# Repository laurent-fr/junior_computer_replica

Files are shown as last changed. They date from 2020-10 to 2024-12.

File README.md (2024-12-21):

# Junior Computer Replica

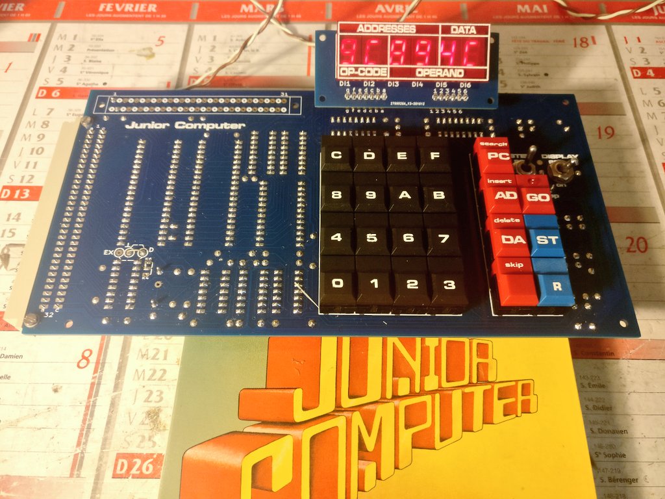
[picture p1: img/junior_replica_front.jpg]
Junior Computer Front


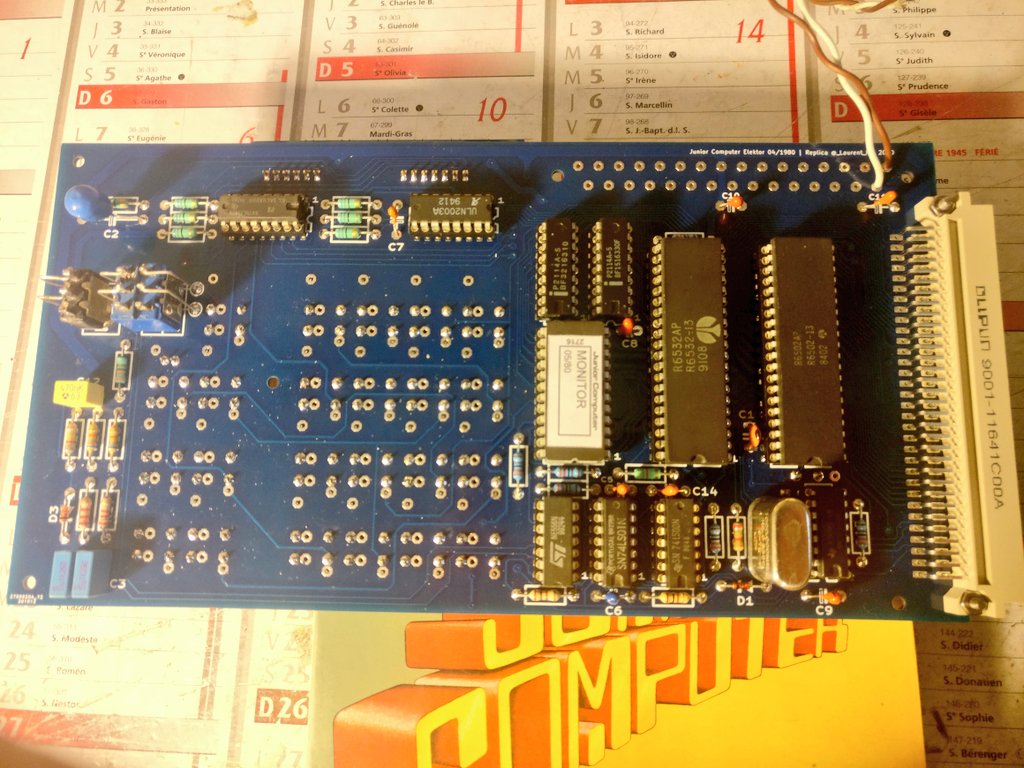
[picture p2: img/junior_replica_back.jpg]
Junior Computer Back


The Junior Computer is a 6502 SBC made by Elektor in 1980. It looks a lot like a KIM-1.

This is a replica PCB I made with KiCAD.

The best source of information for this computer is Elektor Magazine from 80's , but you can find a lot on this website : http://retro.hansotten.nl/6502-sbc/elektuur-junior/

This board is not a 100% accurate replica, because I have added directly on the PCB a few updates published later by Elektor :
* a fix for memory decoding needed for the expansion board
* the main decoupling capacitor C2 was on wrong side of S25 (activate display) which could reset the computer
* a simple reset circuit with a resistor and a capacitor

I also replaced the 2708 EPROM by a 2716, which avoid the need of an hard to find EPROM & EPROM programmer, and has the big benefit of reducing the required power supplies from 3 (+5,-5,+12) to only +5V.

This work is licenced under CC BY-NC-SA (Attribution-NonCommercial-ShareAlike)

## BOM

| Qty | Reference | Value | Comment |
| --- | --- | --- | --- |
| 1	| C1 |	10p | |
| 1	| C2 |	47µ 6V tantale | |
| 2	| C3, C4 |	100n MKH
| 8	| C5...C9, C10, C11, C14 | 	1µ 16V tantale | |
| 1	| C12 |	470nF MKH | |
| 2	| D1, D3 |	1N4148 | |
| 1	| IC1 |	MC6502 | |
| 1	| IC10 |	74LS01 | |
| 1	| IC11 |	ULN2003 | |
| 1	| IC2 |	2716 | |
| 1	| IC3 |	MC6532 | probably the first part to look at ! |
| 2	| IC4 IC5 |	2114 | static RAM, search on Ebay |
| 2	| IC7 IC6 |	74LS145 | |
| 1	| IC8 |	NE556 | |
| 1	| IC9 |	74LS00 | |
| 1	| J2 |	DIN41612 32 A+C angled male| |
| 1	| J3 |	DIN41617-31 straight female | |
| 2	| R17 R19 |	2k2 | |
| 2	| R18 R20 |	68k | |
| 1 | R1 | 330K | |
| 6	| R2 R3 R4 R16 R14 R15 |	3k3 | |
| 2	| R22 R21 |	1k | |
| 1	| R23 |	820k | |
| 1	| R5 |	4k7 | |
| 1	| R6 |	330 | |
| 7	| R7 R8 R9 R10 R12 R13 R11 |	68 | |
| 21	| S1…S23 |	Digitast 12.7mm | 16 black, 4 red, 1 red with integrated LED, 2 blue, but see below |
| 1	| S24 | DPDT lever switch	| with soldering lugs |
| 1	| S25|	SPDT lever switch | with soldering lugs |
| 1	| X.Tal1 |	1Mhz | can be hard to find ! |
| 3	| Socket DIP-14	| | |
| 3	| Socket DIP-16	| | |
| 2	| Socket DIP-18	| | |
| 1	| Socket DIP-24	| | |
| 2	| Socket DIP-40	| | |
| 6 | Di1 ... Di6 | MAN4640A | 7 segment display |

IF you cannot find 2114 RAMs , you can try the small board on "board adapter" folder (warning : not tested !) which should allow to use a 6116 RAM instead and plugs into the 2114 sockets

The Digitast keys (https://www.digikey.com/catalog/en/partgroup/digitast-series/15959) are the most expensives parts of this project. You can also use square tactile switchs instead (but it's not as pretty !)

An other thing to consider is the marking : the black keys need white marking, which can be hard to do. So think of how you will do the marking before choosing the colors of the keys !

## Ordering the PCB

Use you favorite online PCB seller, and order 2 double-sided PCBs (display + computer) from the KiCad output files.

The real ones from Elektor where blue on component side and red on solder side, but if you order a blue PCB it will be close enough (and very nice).

## Building the computer

The building is pretty straightforward (look at the original documentation). Components are soldered on one side, buttons and disply on the other side.

S24 and S25 switchs needs wires from the switchs lugs to the PCB (I used cutoff of resistor leads)

To connect the display to the main board, I used long SIL connectors (15-20mm long) soldered on both side, then I bent the display to ~30°

Don't forget the two small wire jumpers on front side : one from ground to letter "D" and the other one from K6 to the center pin.

If you want to use the file sticker-juniorcomputer.svg, first install the font "Microgramma D Extended Bold" on your system.

## Programming the EPROM

I use a TL866 II plus for this, but anything that works is OK. 

Program the 2716 with the file 2716_junior_monitor_ram_05_1980.bin

## First tests

The power supply is available on both connectors, you just need 0v and +5V (1amp should be more than enough).

All the display should light up (check that the DISPLAY switch is ON). If you see some display ON, some display OFF, it could be a bad MC6532 (don't ask how I know that ...)

If nothing happens, press the reset switch to start the computer.

Typing numbers on keyboard should update the display.

You can find test programs on http://retro.hansotten.nl

## Going further

It would be great to be able to load and save data, and also to have a serial terminal for typing programs. It's exactly the purpose of the Junior Interface board ! Look into the folder "junior-interface" for more infos !

Now I'm sure you want to run BASIC on the Junior, no problem, just build the memory expansion from "junior-universal-memory" folder and you're good to go !

## Status

### Working

* junior-computer : the computer, built and tested OK
* junior-computer-display: the 7 segments display, built and tested OK
* junior-interface : the 2nd board adding various I/O to the computer, built and tested OK
* junior-internal-conn : internal bus between computer and interface, built and tested OK
* junior-internal-bus : a small PCB for linking the computer and the interface board, built and tested OK
* junior-bus : Elektor expansion bus. Not tested, built and tested OK
* junior-universal-memory : a RAM/EPROM board for the computer, built and tested OK

### Not tested

* ram-adapter : replace 2x2114 by 1x6116 RAM. Not tested

```
Any question ? --> Mastodon @LaurentFr@piaille.fr
```

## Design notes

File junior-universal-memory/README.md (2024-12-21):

# Universal Memory

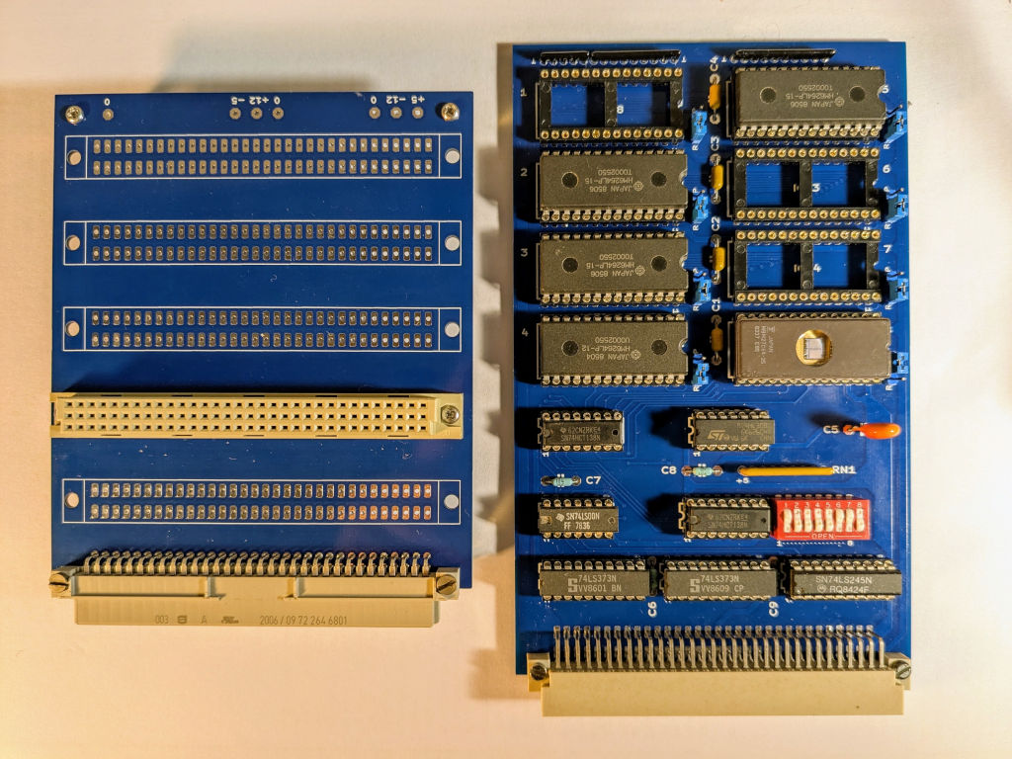
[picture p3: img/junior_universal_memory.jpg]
Universal Memory Card


This board is inspired by Elektor Universal Memory Card published in 1983 http://retro.hansotten.nl/uploads/junior/articlesuk/universalmemoryuk198303.pdf with a different address decoding.

## BOM

| Qty | Reference | Value | Comment |
| --- | --- | --- | --- |
| 8	| C1...C4,C6...C9 | 100n | |
| 1	|C5 | 10µF/16V | |
| 2	| IC1,IC2 |	74LS373 | |
| 1	| IC3 | 74LS245 | |
| 2	| IC4,IC5 | 74LS138 | |
| 1	| IC6 | 74LS00 | |
| 1	|IC7 | 74LS30 | |
| 8	| IC8...IC15 | 6264 and/or 27C64 | see Setup below ! |
| 1	| | Din 41612 male angled | |
| 2	| RN1 | Resistor Network 8x10K | total 9 pins | 
| 1 | |	Resistor Network 8x100K | total 9 pins |
| 1	| | Resistor Network 9x100K | total 10 pins |
| 1	| | Resistor Network 4x100K | total 5 pins |
| 1	| SW1 | DIL switch x8 | |

## Building the board

- be careful about resistor networks orientation
- if you cannot find the various 100K resistor networks you can instead use standard 100K resistors soldered vertically with a common lead on top

You also need to build the "junior-bus" project.

## Setup

You have 8 sockets available, where you can install either 8Kb RAMs (6264) or 8Kb EPROMs (27c64). Each socket is numbered from 1 to 8 and corresponds to 1/8 of total memory space : 

| Socket # | Memory range |
| --- | --- |
| 1 | 0x0000 to 0x1FFF |
| 2 | 0x2000 to 0x3FFF |
| 3 | 0x4000 to 0x5FFF |
| 4 | 0x6000 to 0x7FFF |
| 5 | 0x8000 to 0x9FFF |
| 6 | 0xA000 to 0xBFFF |
| 7 | 0xC000 to 0xDFFF |
| 8 | 0xE000 to 0xFFFF |

Every time you install a RAM or an EPROM, set the corresponding jumper accordingly (R for RAM and P for (E)PROM).

On SW1, every switch corresponding to an empty socket must be OPENED, close the others.

Socket 1 cannot be used (for now ...) because it's address space is used by the Junior Computer and the interface.

You need to put an EPROM in socket 8 because reset vectors are now handled by this board. You just need to program the 6 last bytes, the remaining space is free to use. By default I suggest putting 0xFF on all un-used bytes.

| EPROM addr | Memory addr | Data |
| --- | --- |  --- |
| 0000 | E000 | FF |
| ... | ... | FF |
| 1FF9 | FFF9 | FF |
| 1FFA | FFFA | 2F |
| 1FFB | FFFB | 1F |
| 1FFC | FFFC | 1D |
| 1FFD | FFFD | 1C |
| 1FFE | FFFE | 32 |
| 1FFF | FFFF | 1F |

To run BASIC you will need at least 2 RAMs in sockets 2&3 (16Kb total), but you will have more space with 4 RAMS (sockets 2 to 5, 32Kb total).

## Junior address decoding update

By default the Junior Computer only decodes 8Kb of memory, ignoring A13,A14 and A15 addresses. This means that every address content is repeated 8 times, every 8Kb. This is why the reset vectors in the Junior EPROM at address 0x1FFE and 0x1FFF are also seen at 0xFFFE and 0xFFFF, which allows the computer to boot.

The problem with this address decoding is that our memory card cannot be seen by the computer, because it cannot see anything above the first 8Kb !

To solve this an improved address decoding has been added to the Junior interface, to activate it you need to do 2 things :

- on the Junior Computer, move the Jumper from GND-D to EX-D
- on the Junior Interface, move the jumper from T-S to S-R

Now the computer is able to decode full 64Kb memory (and won't start without the memory board !)

## Test

Connect the bus to the Junior interface, the the memory card to the bus and power on the computer.
It should start at usual.

With the keypad you can try to read and write memory on addresses corresponding to RAM.

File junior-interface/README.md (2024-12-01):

depp# Junior Computer Replica

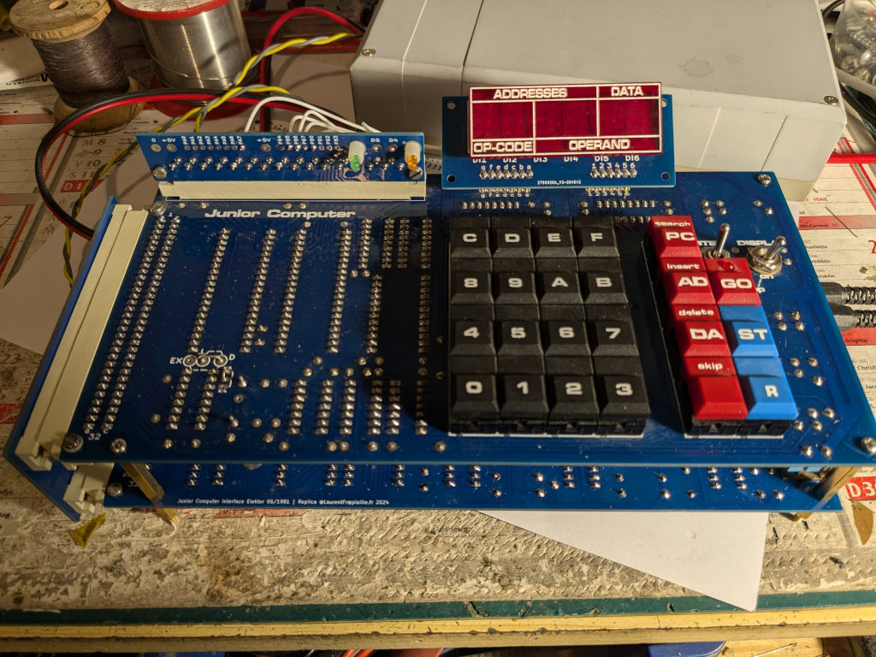
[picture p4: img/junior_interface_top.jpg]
Junior Computer Interface Top Junior Interface Top


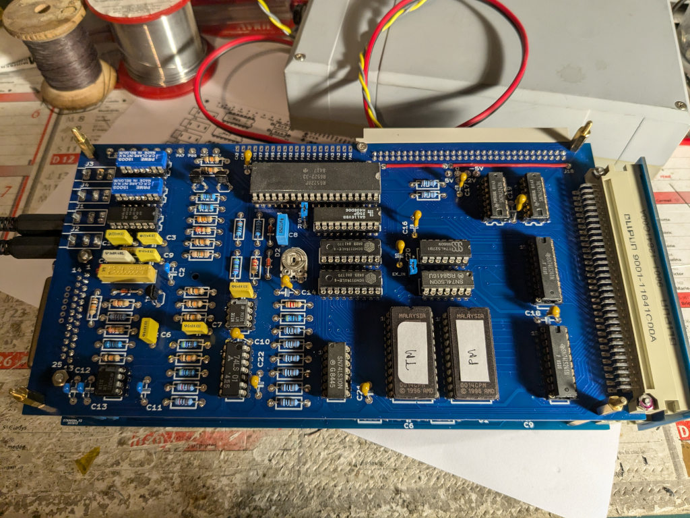
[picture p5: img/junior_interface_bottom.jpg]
Junior Computer Interface Bottom Junior Interface Bottom


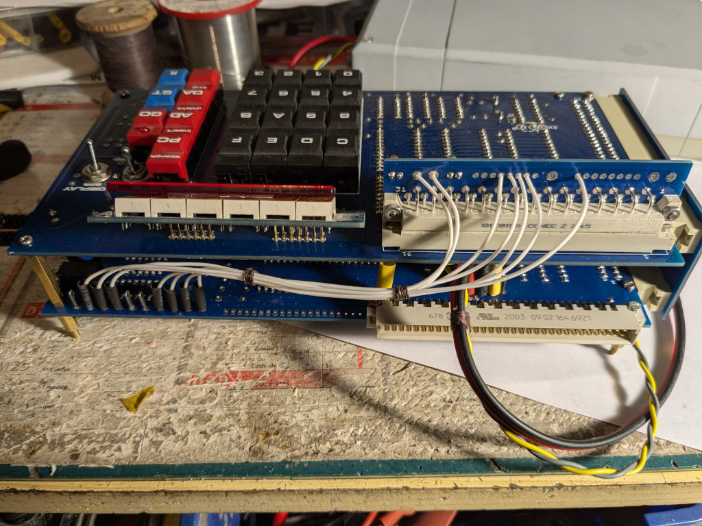
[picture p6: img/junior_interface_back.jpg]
Junior Computer Inerface Back Junior Interface Back


This is a replica of the expansion board for the Junior Computer, published in Elektor magazine in 1981

This is a replica PCB I made with KiCAD.

The best source of information for this computer is Elektor Magazine from 80's , but you can find a lot on this website : http://retro.hansotten.nl/6502-sbc/elektuur-junior/

I made some changes from the original :
* The board can only use 2716 Eproms, no 1K ROM or 1K EPROM 
* The PROM used for bus read/write signals is replaced by a GAL
* The RCA connectors for the tape are replaced by smaller 3.5mm jacks, which allows a better placement of DB25 connector

This work is licenced under CC BY-NC-SA (Attribution-NonCommercial-ShareAlike)

## BOM

| Qty | Reference | Value | Comment |
| --- | --- | --- | --- |
|1	|C1	|220n | |
|4	|C2,C11,C12,C13	|10uF 16V | |
|1	|C3	|22n | |
|1	|C4	|1n | |
|3	|C5,C6,C7	|6n8 | |
|1	|C8	|100n | |
|1	|C9	|47n | |
|10	|C10,C14,C15,C16,C17,C18,C19,C20,C21,C22	|1uF 16V | |
|3	|D1,D2,D3	|1N4148 | |
|1	|IC1	|6522 | |
|2	|IC2,IC3	|2114 | |
|2	|IC4,IC5	|2716 | |
|1	|IC6	|NE565 | |
|2	|IC7,IC8	|LM311 | |
|2	|IC9,IC10	|74LS241 | |
|2	|IC11,IC12	|74LS243 | |
|1	|IC13	|74LS27 | |
|1	|IC14	|74LS01 | |
|1	|IC15	|74LS30 | |
|1	|IC16	|74LS00 | |
|1	|IC17	|GAL16V8 | |
|4	|J1,J2,J3,J4	|Jack 3.5mm |
|1	|J6	|C64AC | |
|1	|J7	|C64AB | |
|1	|J10	|DB25_Female | |
|1	|P1	|5k  multitour | |
|1	|P2	|1k | |
|8	|R1,R2,R3,R4,R32,R33,R34,R35	|1K | |
|1	|R5	|22k | |
|9	|R6,R10,R11,R14,R15,R24,R26,R27,R28	|10k | |
|3	|R7,R8,R36	|8k2 | |
|4	|R9,R18,R22,R23	|4k7 | |
|1	|R12	|6k8 | |
|3	|R13,R25,R31	|2k2 | |
|1	|R16	|100 | |
|1	|R17	|330 | |
|1	|R19	|470 | |
|1	|R20	|1k2 | |
|1	|R21	|15k | |
|1	|R29	|33k | |
|1	|R30	|4M7 | |
|1	|R37	|33 | |
|2	|Re1,Re2	|relay_reed | |
|1	|T1	|BC547 | |
|2	|T2,T3	|BC516 | |

## Building the interface

Nothing special here, juste be careful : J1..J4 , J7 and J10 are on solder side. Do not forget the 2 wires jumpers near J7.

Put a jumper between the center pin and "Ex_in" and an other one between "T" and "S"

You will also need to build the projects "junior-internal-bus" and "junior-interface-conn". 

The internal bus is simply 2 DIN41612 connectors, just be careful to solder the connectors correctly : the ground plane should be on solder side, and look at where are +5V and GND to avoid soldering the board upside down.

The interface connector is a small PCB to connect the top left connector of the Junior Computer to the pins on the interface board. Just put a wire on signals with the same name on both side. You don't need to connect GND and +5V, they are already available on the internal bus.

You will also need a +5V power supply (at least 1A, let's say 2A to be safe) and +12V/-12V (400mA is more than enough).

## Programming 

Program the GAL with the .jed file in the "GAL" folder (again the TL866 II plus can do the job)

Program the 2 eproms "TM" and "PM" with "TM ESS506.bin" and "PM ESS507.bin" from 'eproms' folder

## First tests

Once everything is connected together (look at the pictures on the top of this page), the Junior Computer should power up as usual.

You should be able to read and write data between $0200 and $03FF (the new 1K RAM), and read EPROM data at $0800 and $1000 (compare the firsts bytes with the .bin files contents)

To setup the tape and the serial interfaces, you can follow the original articles availble at http://retro.hansotten.nl/6502-sbc/elektuur-junior/elektor-junior-literature/

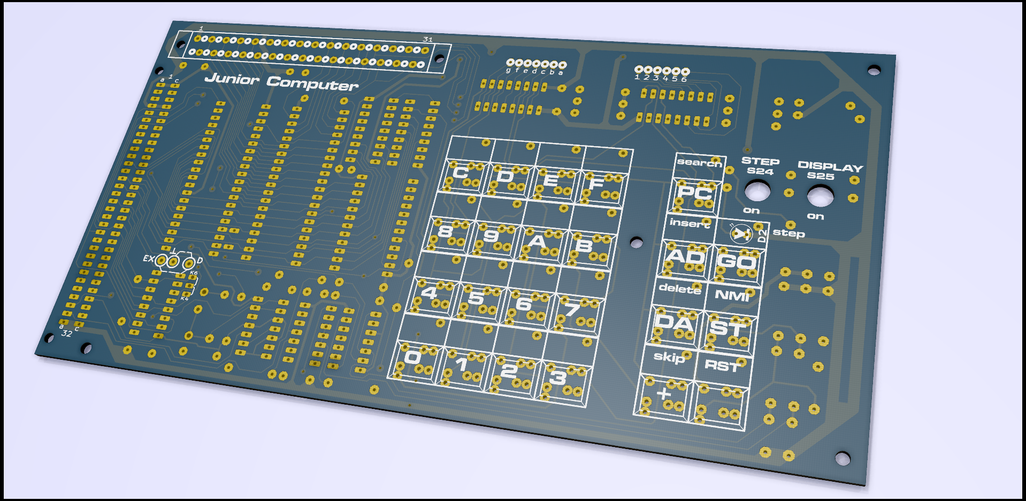
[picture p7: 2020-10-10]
junior-computer-1.png

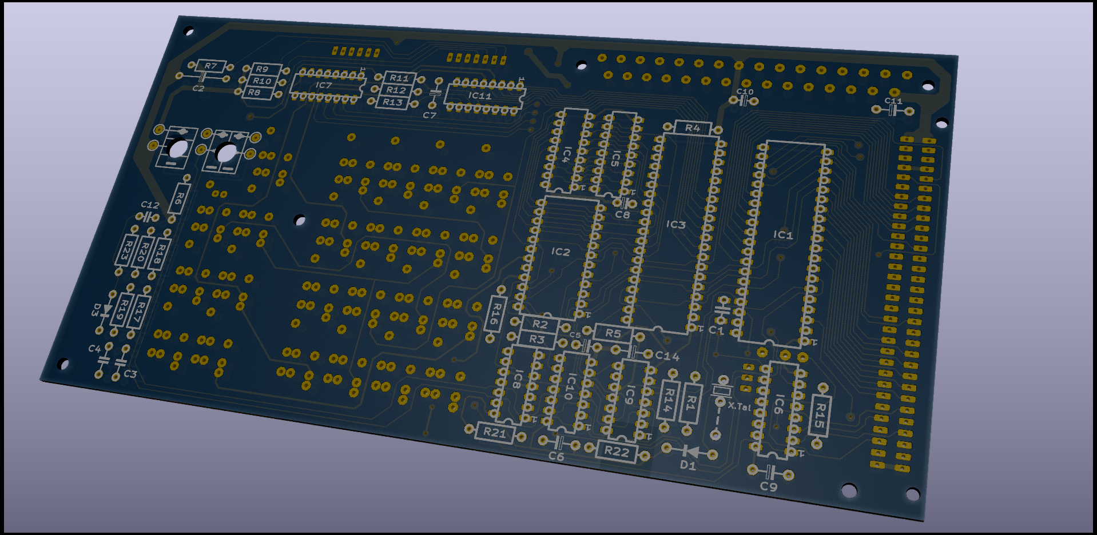
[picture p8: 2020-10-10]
junior-computer-2.png

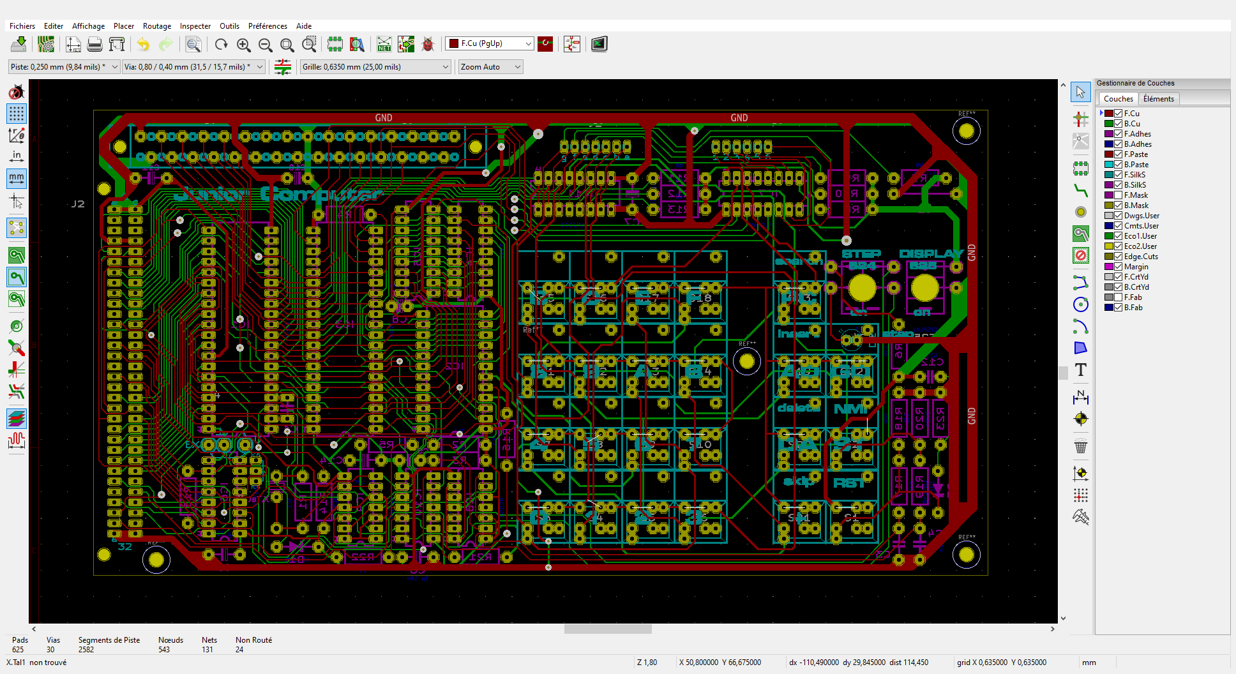
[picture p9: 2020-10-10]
typon.png

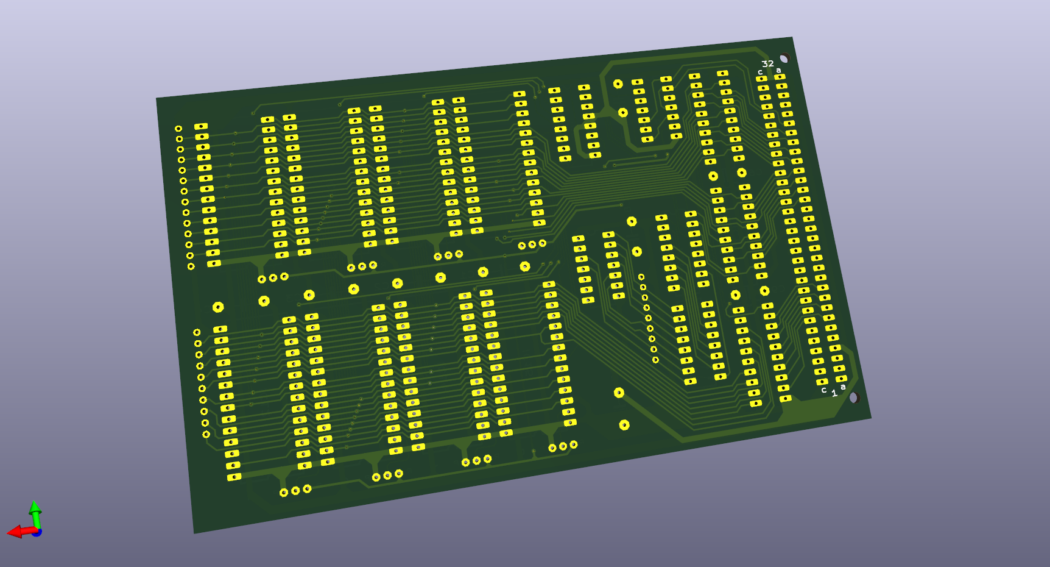
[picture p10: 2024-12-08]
junior-universal-memory/kicad/junior-universal-memory-2.png

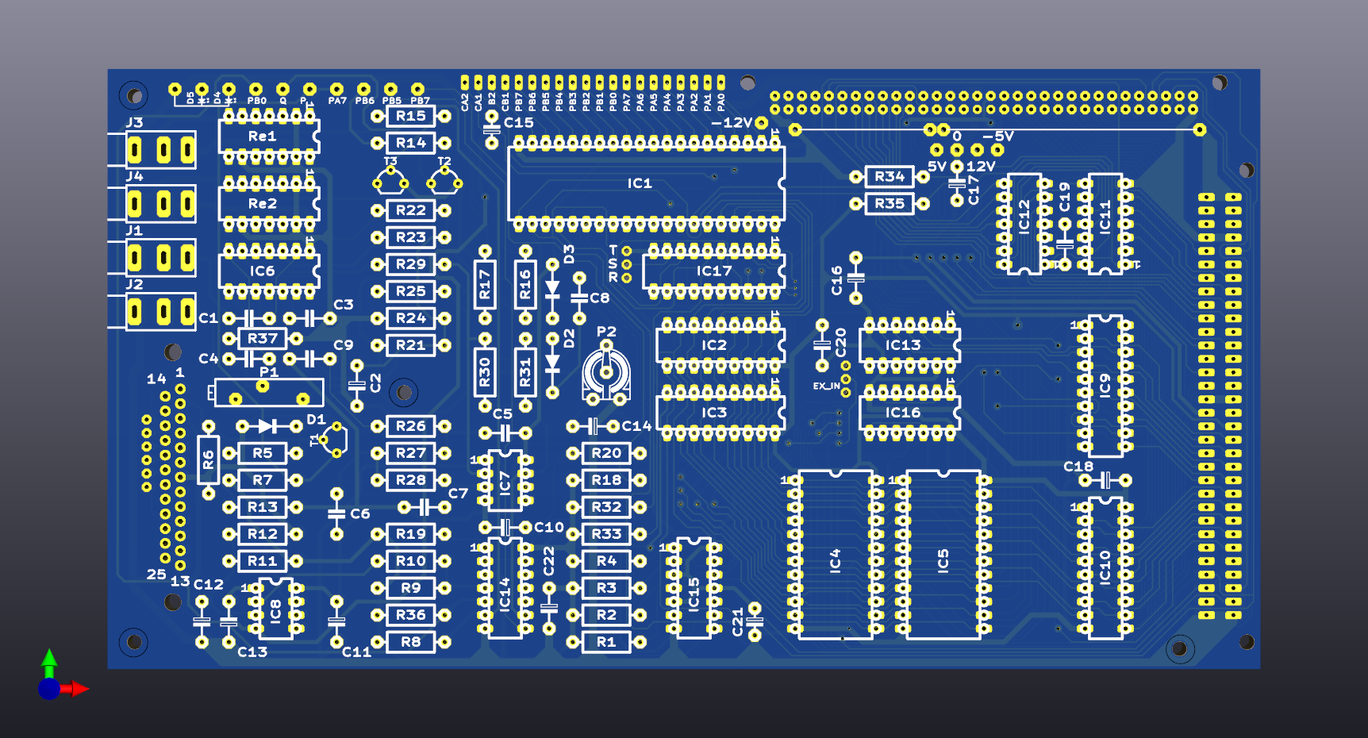
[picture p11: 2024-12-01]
junior-interface/junior-interface/junior-interface.png

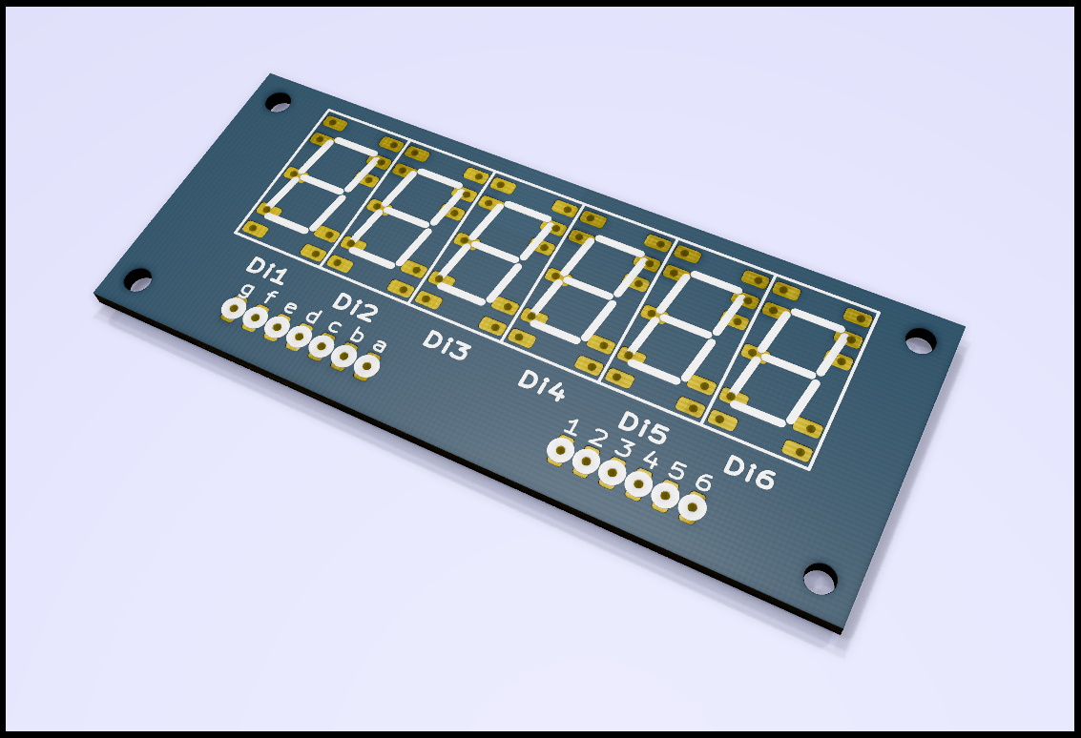
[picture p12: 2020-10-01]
junior-computer-display/junior-computer-display-front.png

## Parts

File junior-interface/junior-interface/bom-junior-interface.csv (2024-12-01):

Reference | Value | Datasheet | Footprint | Qty | DNP
C1 | 220n | ~ | elektor:CAP-3 | 1
C2,C11,C12,C13 | 10uF 16V | ~ | elektor:CAP-POL-3 | 4
C3 | 22n | ~ | elektor:CAP-3 | 1
C4 | 1n | ~ | elektor:CAP-3 | 1
C5,C6,C7 | 6n8 | ~ | elektor:CAP-3 | 3
C8 | 100n | ~ | elektor:CAP-3 | 1
C9 | 47n | ~ | elektor:CAP-3 | 1
C10,C14,C15,C16,C17,C18,C19,C20,C21,C22 | 1uF 16V | ~ | -- valeurs mixtées -- | 10
D1,D2,D3 | 1N4148 | ~ | elektor:Diod-4 | 3
IC1 | 6522 |  | elektor:DIL-40 | 1
IC2,IC3 | 2114 |  | elektor:DIL-18 | 2
IC4,IC5 | 2716 |  | elektor:DIL-24 | 2
IC6 | NE565 |  | elektor:DIL-14 | 1
IC7,IC8 | LM311 | http://www.ti.com/lit/ds/symlink/lm311.pdf | elektor:DIL-8 | 2
IC9,IC10 | 74LS241 | http://www.ti.com/lit/gpn/sn74LS241 | elektor:DIL-20 | 2
IC11,IC12 | 74LS243 | http://www.ti.com/lit/gpn/sn74LS243 | elektor:DIL-14 | 2
IC13 | 74LS27 | http://www.ti.com/lit/gpn/sn74LS27 | elektor:DIL-14 | 1
IC14 | 74LS01 | http://www.nteinc.com/specs/7400to7499/pdf/nte74LS01.pdf | elektor:DIL-14 | 1
IC15 | 74LS30 | http://www.ti.com/lit/gpn/sn74LS30 | elektor:DIL-14 | 1
IC16 | 74LS00 | http://www.ti.com/lit/gpn/sn74ls00 | elektor:DIL-14 | 1
IC17 | GAL16V8 |  | elektor:DIL-20 | 1
J1,J2,J3,J4 | Conn_01x03_Socket | ~ | elektor:Support-Jack-3.5 | 4
J5,J17,J18,J19,J20,J21,J22,J23,J27,J40 |  | ~ | -- valeurs mixtées -- | 10
J6 | C64AC | ~ | elektor:DIN-41612-AC | 1
J7 | C64AB | ~ | elektor:DIN-41612-AB | 1
J8 | +5V | ~ | elektor:CONN-1 | 1
J10 | DB25_Female | ~ | elektor:DB25-F-CI | 1
J11 | Conn_01x20_Male | ~ | elektor:Conn-20-L | 1
J12,J30 | Conn_01x03_Male | ~ | elektor:CONN-3 | 2
J13 | +12V | ~ | elektor:CONN-1 | 1
J14 | -5V | ~ | elektor:CONN-1 | 1
J15 | -12V | ~ | elektor:CONN-1 | 1
J16 | 0 | ~ | elektor:CONN-1 | 1
J24 | P | ~ | elektor:CONN-1 | 1
J25 | Q | ~ | elektor:CONN-1 | 1
J26 | D4 | ~ | elektor:CONN-1 | 1
J28 | D5 | ~ | elektor:CONN-1 | 1
J29 | Conn_01x06_Male | ~ | elektor:CONN-6 | 1
P1 | 5k | ~ | elektor:POT-MULTITOUR | 1
P2 | 1k | ~ | elektor:POT | 1
R1,R2,R3,R4,R32,R33,R34,R35 | 1K | ~ | elektor:Res-5 | 8
R5 | 22k | ~ | elektor:Res-5 | 1
R6,R10,R11,R14,R15,R24,R26,R27,R28 | 10k | ~ | elektor:Res-5 | 9
R7,R8,R36 | 8k2 | ~ | elektor:Res-5 | 3
R9,R18,R22,R23 | 4k7 | ~ | elektor:Res-5 | 4
R12 | 6k8 | ~ | elektor:Res-5 | 1
R13,R25,R31 | 2k2 | ~ | elektor:Res-5 | 3
R16 | 100 | ~ | elektor:Res-5 | 1
R17 | 330 | ~ | elektor:Res-5 | 1
R19 | 470 | ~ | elektor:Res-5 | 1
R20 | 1k2 | ~ | elektor:Res-5 | 1
R21 | 15k | ~ | elektor:Res-5 | 1
R29 | 33k | ~ | elektor:Res-5 | 1
R30 | 4M7 | ~ | elektor:Res-5 | 1
R37 | 33 | ~ | elektor:Res-5 | 1
Re1,Re2 | relay_reed | https://standexelectronics.com/wp-content/uploads/datasheet_reed_relay_SIL.pdf | elektor:DIL-14 | 2
T1 | BC547 | http://www.fairchildsemi.com/ds/BC/BC547.pdf | elektor:TO-92 | 1
T2,T3 | BC516 | http://www.fairchildsemi.com/ds/BC/BC516.pdf | elektor:TO-92 | 2

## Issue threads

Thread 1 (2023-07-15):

Junior interface board PA0 to PB7 connection

robvb, 2023-07-15:
Hello LaurantFR,

Can you confirm the Junior Interface card is working ..

BR rob

laurent-fr, 2023-07-23:
Hi Rob,
I've not yet built the interface and I can't guarantee it's OK, I still have the components for this board ready to use but I did not took the time yet to order the pcb and test it (too many projects, too little time !)
Laurent

robvb, 2023-07-23:
Bonjour Laurent,

First of all ,,  thank you for the beautiful work on the Junior Computer.
I ordered some of your interfaces pcb's (expected delivery,next week) and I could send you 2 pcs  (free of charge)  ;-)

BR rob

laurent-fr, 2023-07-28:
Hi Rob,
thanks :-) Have you built the Junior card ? (this one should work !)
I really hope there is no too much mistakes on the extension board (the GAL that replaces the PROM needs testing, and I remember I was not completely happy with the chip selects)

Closed 2023-07-16.

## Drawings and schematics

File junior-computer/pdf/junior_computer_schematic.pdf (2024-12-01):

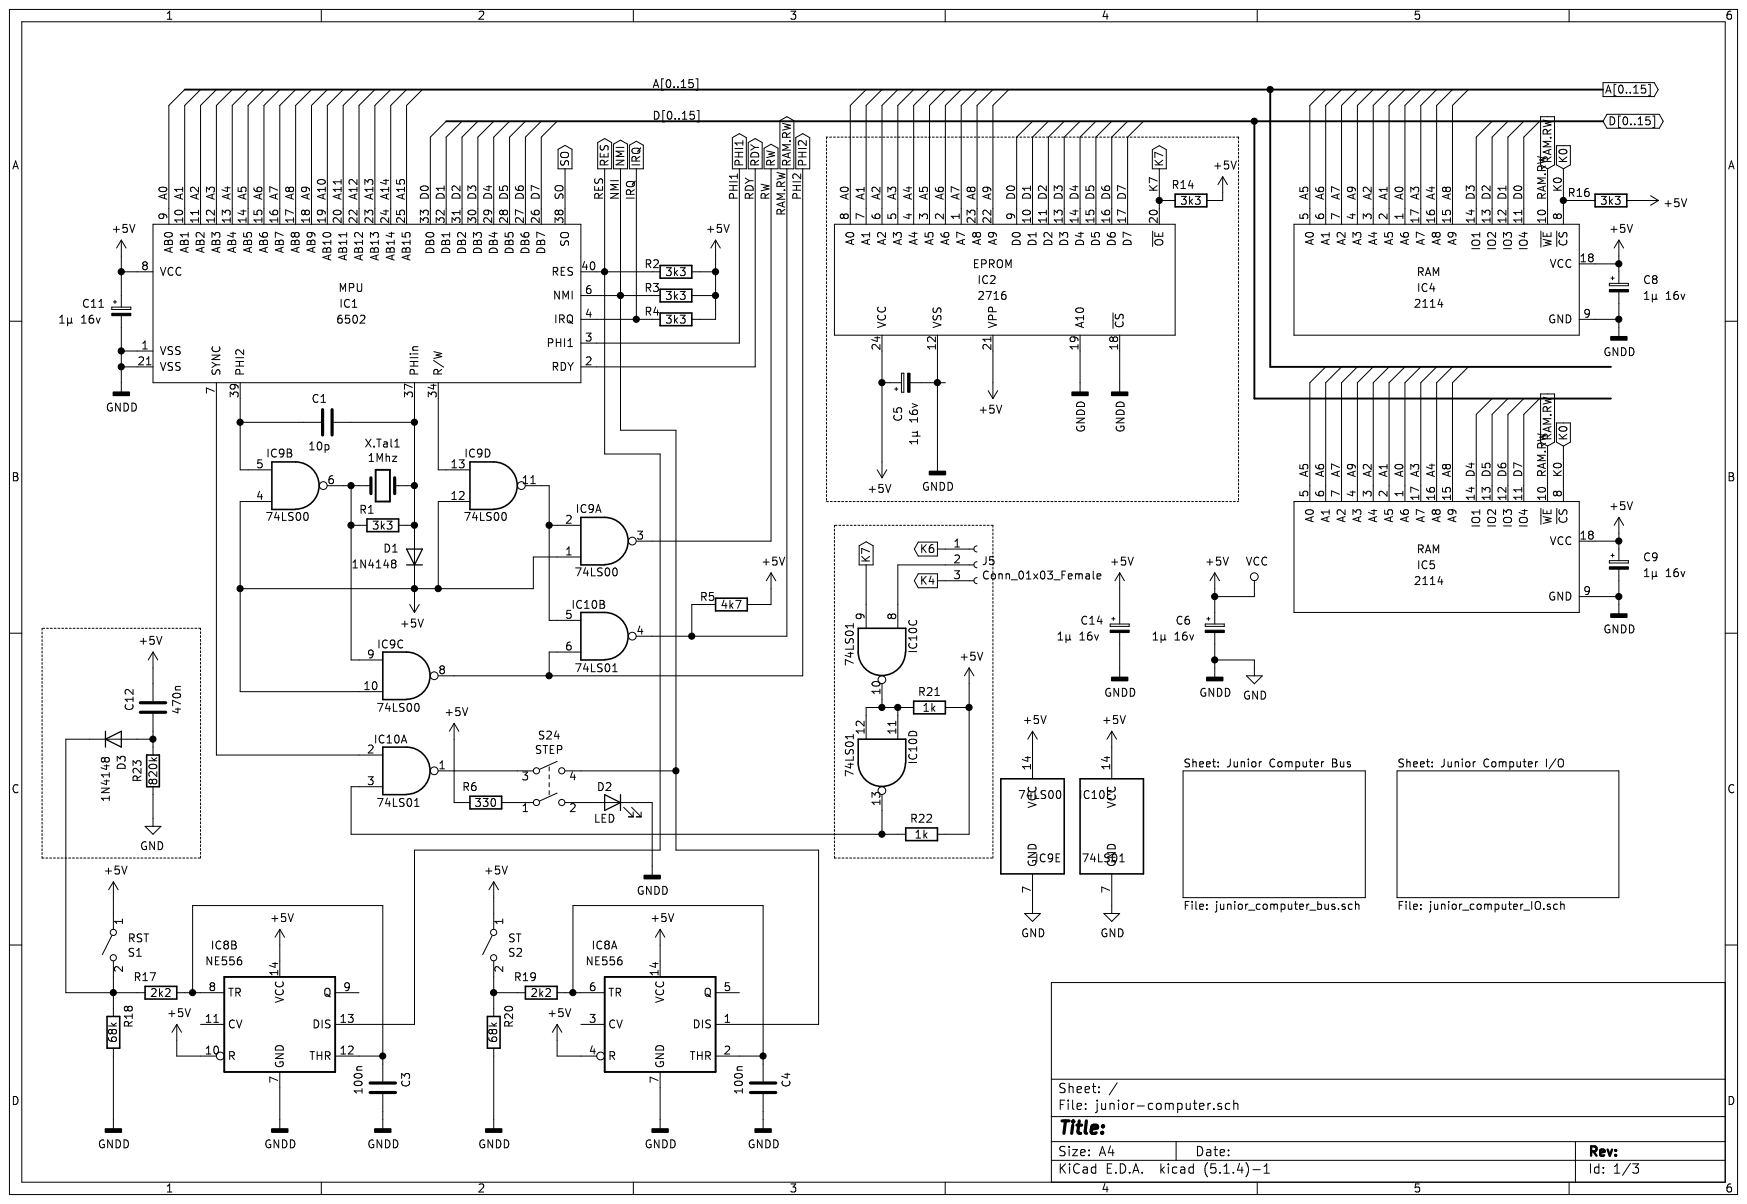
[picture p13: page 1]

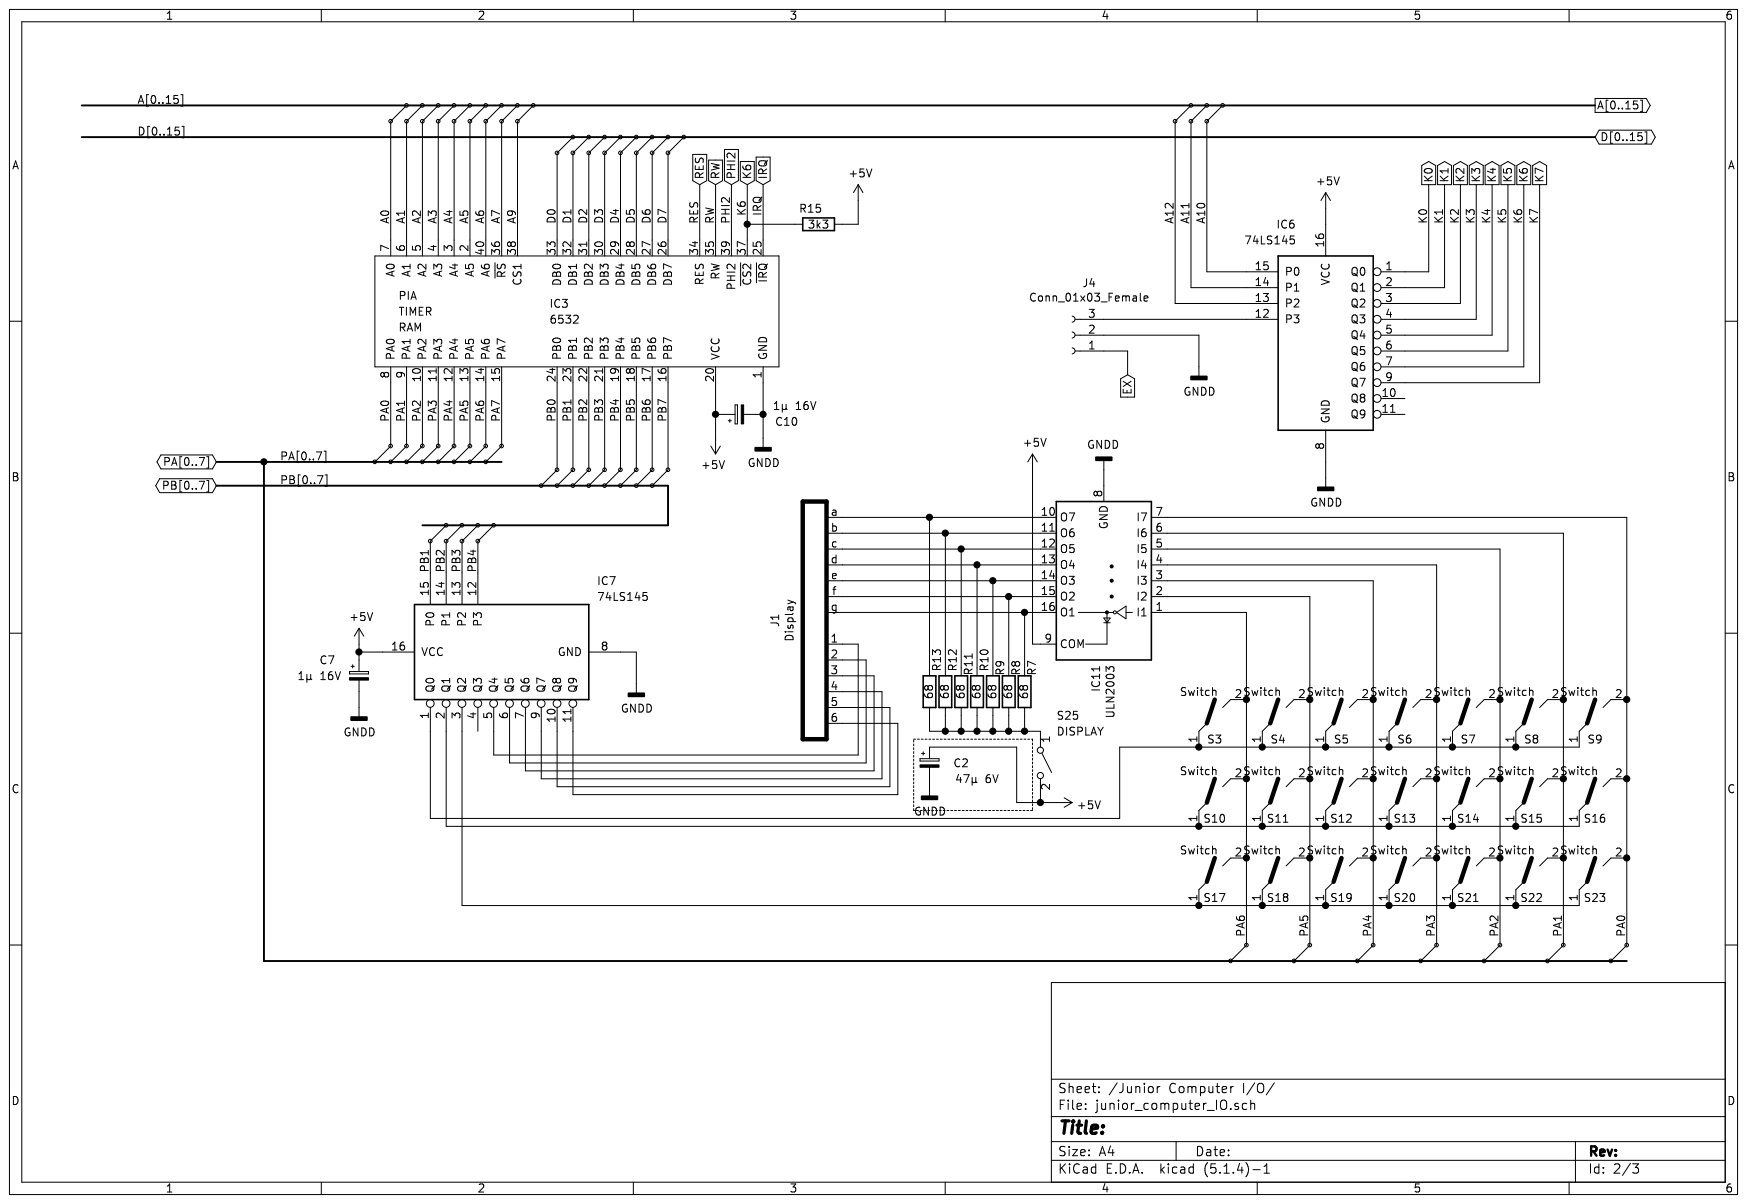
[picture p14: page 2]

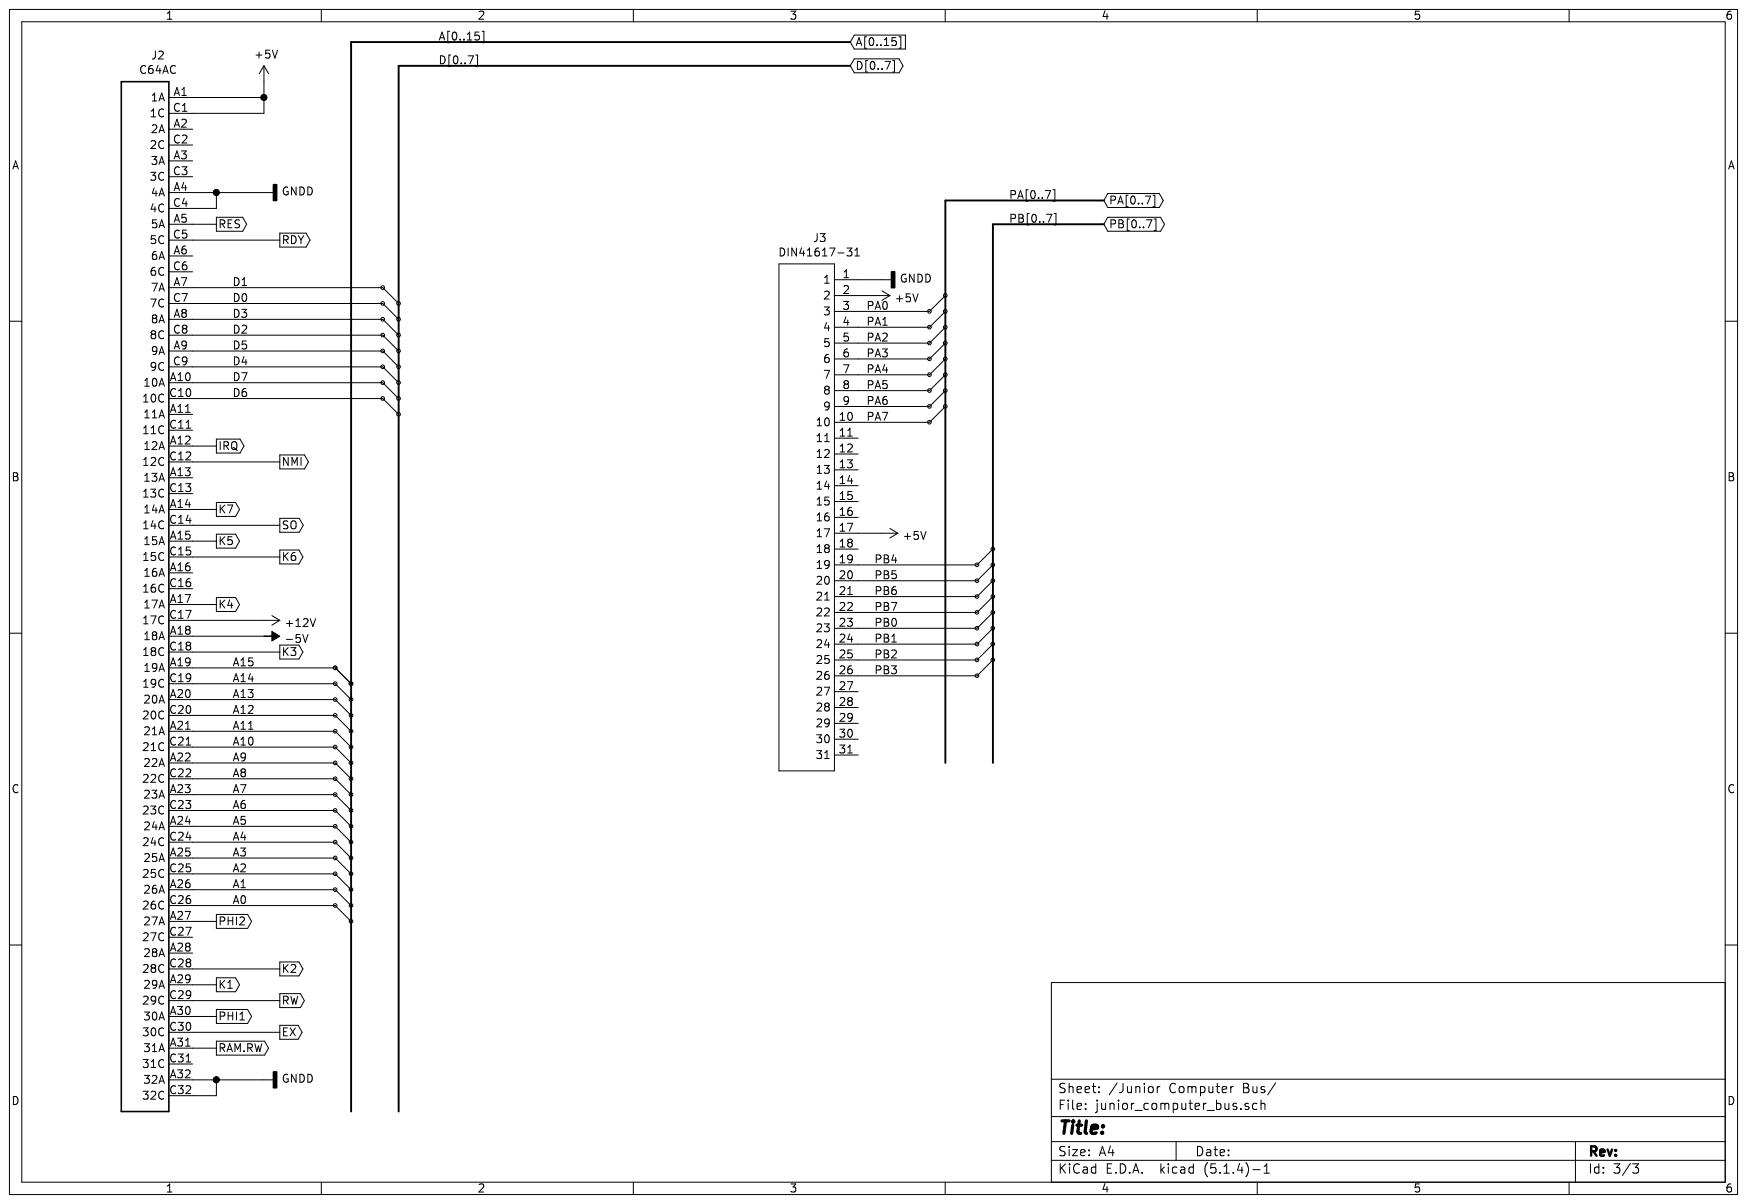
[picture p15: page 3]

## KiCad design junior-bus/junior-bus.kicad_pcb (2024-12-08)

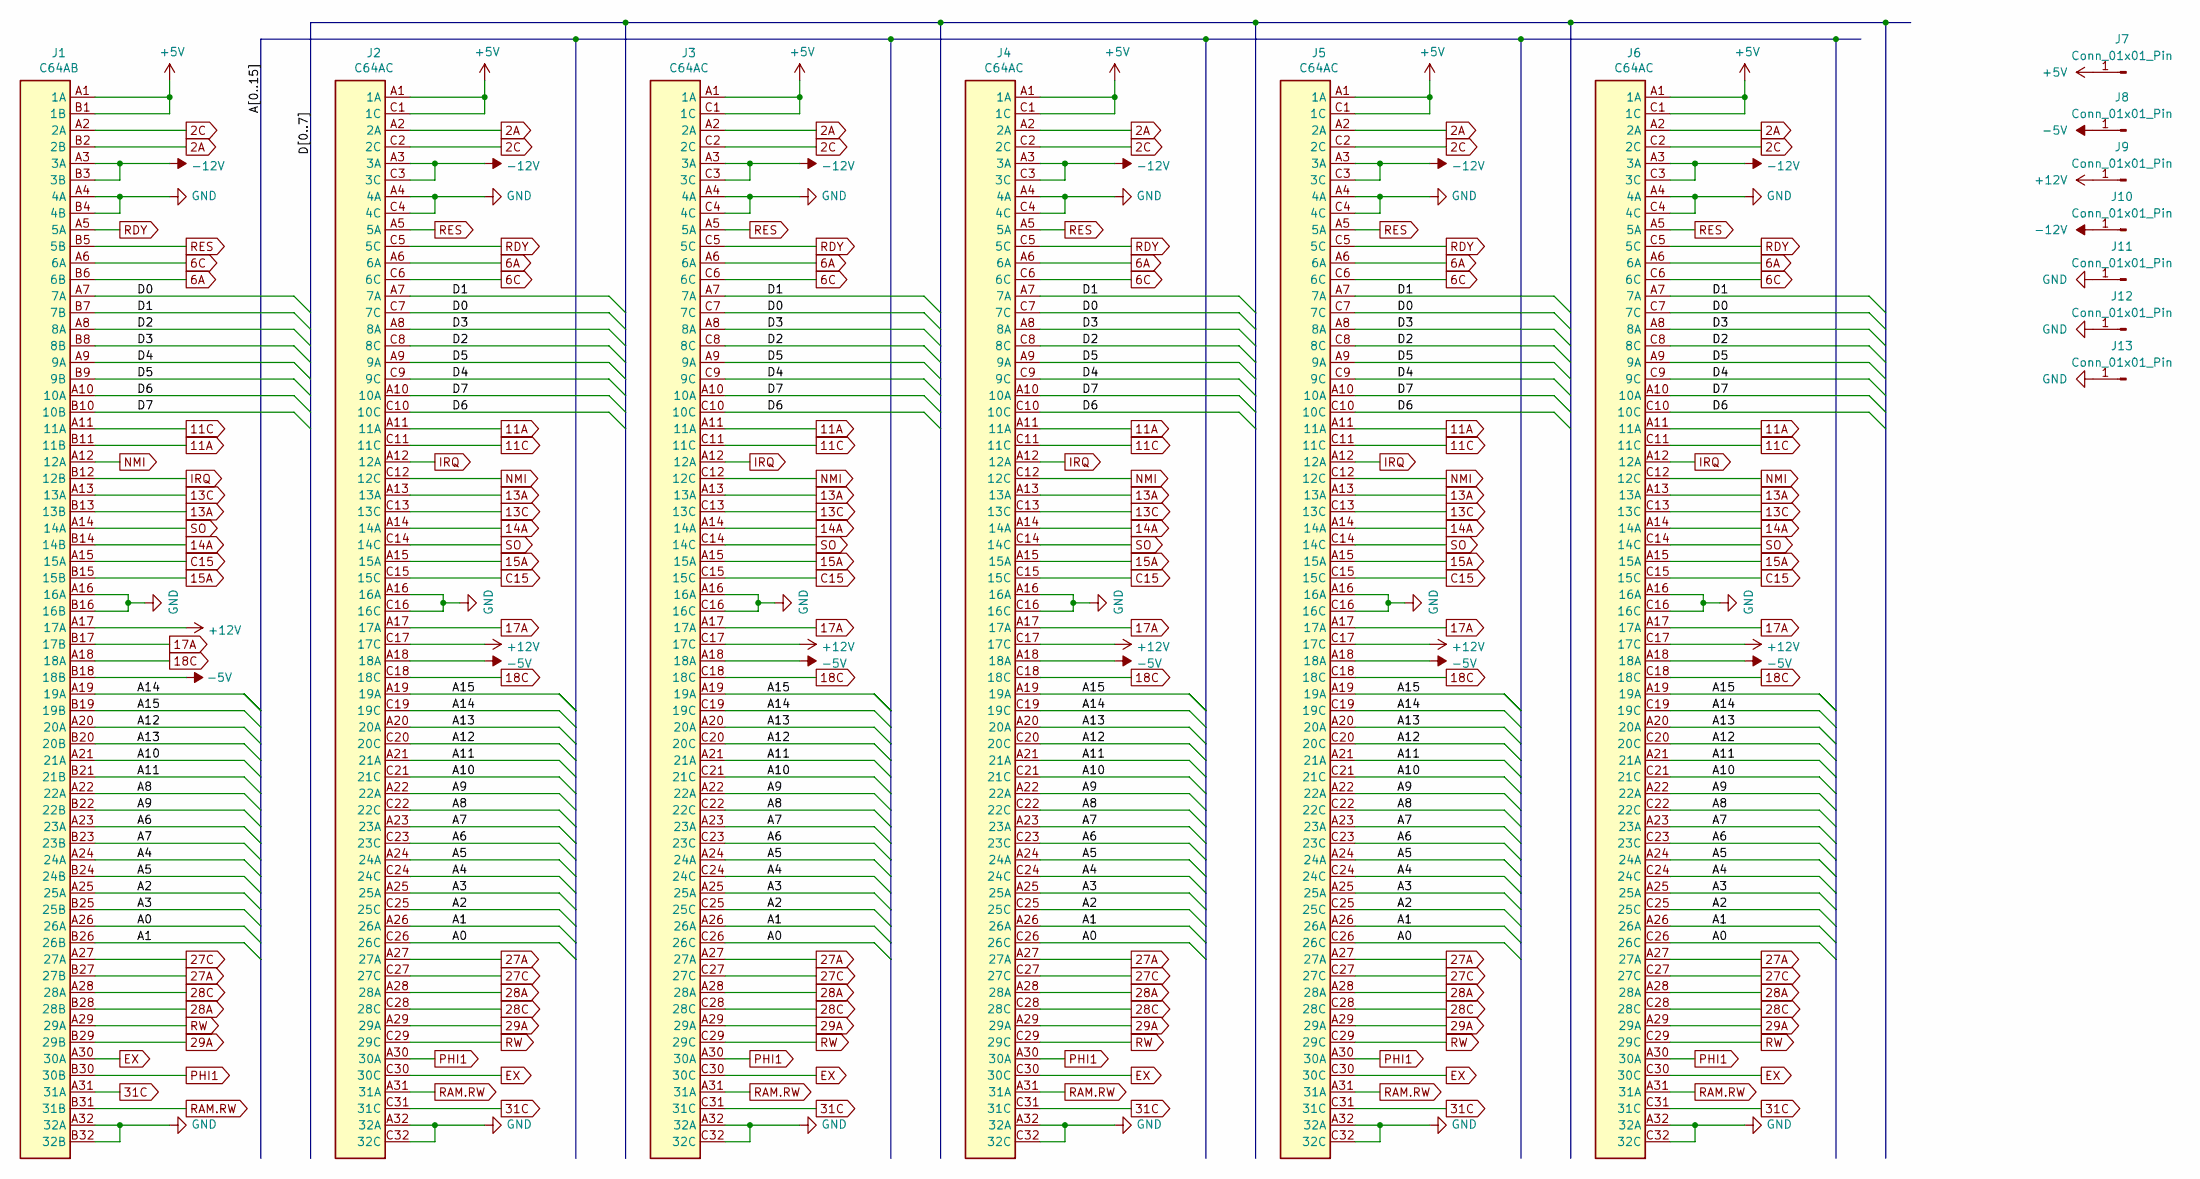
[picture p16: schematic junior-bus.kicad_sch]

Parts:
J1: C64AB; DIN-41612-AB-small-pads
J2, J3, J4, J5, J6: C64AC; DI41612-AC-F
J7, J8, J9, J10, J11, J12, J13: Conn_01x01_Pin; PIN

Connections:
2A: J1.B2 (2B), J2.A2 (2A), J3.A2 (2A), J4.A2 (2A), J5.A2 (2A), J6.A2 (2A)
2C: J1.A2 (2A), J2.C2 (2C), J3.C2 (2C), J4.C2 (2C), J5.C2 (2C), J6.C2 (2C)
6A: J1.B6 (6B), J2.A6 (6A), J3.A6 (6A), J4.A6 (6A), J5.A6 (6A), J6.A6 (6A)
6C: J1.A6 (6A), J2.C6 (6C), J3.C6 (6C), J4.C6 (6C), J5.C6 (6C), J6.C6 (6C)
11A: J1.B11 (11B), J2.A11 (11A), J3.A11 (11A), J4.A11 (11A), J5.A11 (11A), J6.A11 (11A)
11C: J1.A11 (11A), J2.C11 (11C), J3.C11 (11C), J4.C11 (11C), J5.C11 (11C), J6.C11 (11C)
13A: J1.B13 (13B), J2.A13 (13A), J3.A13 (13A), J4.A13 (13A), J5.A13 (13A), J6.A13 (13A)
13C: J1.A13 (13A), J2.C13 (13C), J3.C13 (13C), J4.C13 (13C), J5.C13 (13C), J6.C13 (13C)
14A: J1.B14 (14B), J2.A14 (14A), J3.A14 (14A), J4.A14 (14A), J5.A14 (14A), J6.A14 (14A)
15A: J1.B15 (15B), J2.A15 (15A), J3.A15 (15A), J4.A15 (15A), J5.A15 (15A), J6.A15 (15A)
17A: J1.B17 (17B), J2.A17 (17A), J3.A17 (17A), J4.A17 (17A), J5.A17 (17A), J6.A17 (17A)
18C: J1.A18 (18A), J2.C18 (18C), J3.C18 (18C), J4.C18 (18C), J5.C18 (18C), J6.C18 (18C)
27A: J1.B27 (27B), J2.A27 (27A), J3.A27 (27A), J4.A27 (27A), J5.A27 (27A), J6.A27 (27A)
27C: J1.A27 (27A), J2.C27 (27C), J3.C27 (27C), J4.C27 (27C), J5.C27 (27C), J6.C27 (27C)
28A: J1.B28 (28B), J2.A28 (28A), J3.A28 (28A), J4.A28 (28A), J5.A28 (28A), J6.A28 (28A)
28C: J1.A28 (28A), J2.C28 (28C), J3.C28 (28C), J4.C28 (28C), J5.C28 (28C), J6.C28 (28C)
29A: J1.B29 (29B), J2.A29 (29A), J3.A29 (29A), J4.A29 (29A), J5.A29 (29A), J6.A29 (29A)
31C: J1.A31 (31A), J2.C31 (31C), J3.C31 (31C), J4.C31 (31C), J5.C31 (31C), J6.C31 (31C)
+5V: J1.A1 (1A), J1.B1 (1B), J2.A1 (1A), J2.C1 (1C), J3.A1 (1A), J3.C1 (1C), J4.A1 (1A), J4.C1 (1C), J5.A1 (1A), J5.C1 (1C), J6.A1 (1A), J6.C1 (1C), J7.1
+12V: J1.A17 (17A), J2.C17 (17C), J3.C17 (17C), J4.C17 (17C), J5.C17 (17C), J6.C17 (17C), J9.1
-5V: J1.B18 (18B), J2.A18 (18A), J3.A18 (18A), J4.A18 (18A), J5.A18 (18A), J6.A18 (18A), J8.1
-12V: J1.A3 (3A), J1.B3 (3B), J2.A3 (3A), J2.C3 (3C), J3.A3 (3A), J3.C3 (3C), J4.A3 (3A), J4.C3 (3C), J5.A3 (3A), J5.C3 (3C), J6.A3 (3A), J6.C3 (3C), J10.1
/A0: J1.A26 (26A), J2.C26 (26C), J3.C26 (26C), J4.C26 (26C), J5.C26 (26C), J6.C26 (26C)
/A1: J1.B26 (26B), J2.A26 (26A), J3.A26 (26A), J4.A26 (26A), J5.A26 (26A), J6.A26 (26A)
/A2: J1.A25 (25A), J2.C25 (25C), J3.C25 (25C), J4.C25 (25C), J5.C25 (25C), J6.C25 (25C)
/A3: J1.B25 (25B), J2.A25 (25A), J3.A25 (25A), J4.A25 (25A), J5.A25 (25A), J6.A25 (25A)
/A4: J1.A24 (24A), J2.C24 (24C), J3.C24 (24C), J4.C24 (24C), J5.C24 (24C), J6.C24 (24C)
/A5: J1.B24 (24B), J2.A24 (24A), J3.A24 (24A), J4.A24 (24A), J5.A24 (24A), J6.A24 (24A)
/A6: J1.A23 (23A), J2.C23 (23C), J3.C23 (23C), J4.C23 (23C), J5.C23 (23C), J6.C23 (23C)
/A7: J1.B23 (23B), J2.A23 (23A), J3.A23 (23A), J4.A23 (23A), J5.A23 (23A), J6.A23 (23A)
/A8: J1.A22 (22A), J2.C22 (22C), J3.C22 (22C), J4.C22 (22C), J5.C22 (22C), J6.C22 (22C)
/A9: J1.B22 (22B), J2.A22 (22A), J3.A22 (22A), J4.A22 (22A), J5.A22 (22A), J6.A22 (22A)
/A10: J1.A21 (21A), J2.C21 (21C), J3.C21 (21C), J4.C21 (21C), J5.C21 (21C), J6.C21 (21C)
/A11: J1.B21 (21B), J2.A21 (21A), J3.A21 (21A), J4.A21 (21A), J5.A21 (21A), J6.A21 (21A)
/A12: J1.A20 (20A), J2.C20 (20C), J3.C20 (20C), J4.C20 (20C), J5.C20 (20C), J6.C20 (20C)
/A13: J1.B20 (20B), J2.A20 (20A), J3.A20 (20A), J4.A20 (20A), J5.A20 (20A), J6.A20 (20A)
/A14: J1.A19 (19A), J2.C19 (19C), J3.C19 (19C), J4.C19 (19C), J5.C19 (19C), J6.C19 (19C)
/A15: J1.B19 (19B), J2.A19 (19A), J3.A19 (19A), J4.A19 (19A), J5.A19 (19A), J6.A19 (19A)
/D0: J1.A7 (7A), J2.C7 (7C), J3.C7 (7C), J4.C7 (7C), J5.C7 (7C), J6.C7 (7C)
/D1: J1.B7 (7B), J2.A7 (7A), J3.A7 (7A), J4.A7 (7A), J5.A7 (7A), J6.A7 (7A)
/D2: J1.A8 (8A), J2.C8 (8C), J3.C8 (8C), J4.C8 (8C), J5.C8 (8C), J6.C8 (8C)
/D3: J1.B8 (8B), J2.A8 (8A), J3.A8 (8A), J4.A8 (8A), J5.A8 (8A), J6.A8 (8A)
/D4: J1.A9 (9A), J2.C9 (9C), J3.C9 (9C), J4.C9 (9C), J5.C9 (9C), J6.C9 (9C)
/D5: J1.B9 (9B), J2.A9 (9A), J3.A9 (9A), J4.A9 (9A), J5.A9 (9A), J6.A9 (9A)
/D6: J1.A10 (10A), J2.C10 (10C), J3.C10 (10C), J4.C10 (10C), J5.C10 (10C), J6.C10 (10C)
/D7: J1.B10 (10B), J2.A10 (10A), J3.A10 (10A), J4.A10 (10A), J5.A10 (10A), J6.A10 (10A)
C15: J1.A15 (15A), J2.C15 (15C), J3.C15 (15C), J4.C15 (15C), J5.C15 (15C), J6.C15 (15C)
EX: J1.A30 (30A), J2.C30 (30C), J3.C30 (30C), J4.C30 (30C), J5.C30 (30C), J6.C30 (30C)
GND: J1.A4 (4A), J1.A16 (16A), J1.A32 (32A), J1.B4 (4B), J1.B16 (16B), J1.B32 (32B), J2.A4 (4A), J2.A16 (16A), J2.A32 (32A), J2.C4 (4C), J2.C16 (16C), J2.C32 (32C), J3.A4 (4A), J3.A16 (16A), J3.A32 (32A), J3.C4 (4C), J3.C16 (16C), J3.C32 (32C), J4.A4 (4A), J4.A16 (16A), J4.A32 (32A), J4.C4 (4C), J4.C16 (16C), J4.C32 (32C), J5.A4 (4A), J5.A16 (16A), J5.A32 (32A), J5.C4 (4C), J5.C16 (16C), J5.C32 (32C), J6.A4 (4A), J6.A16 (16A), J6.A32 (32A), J6.C4 (4C), J6.C16 (16C), J6.C32 (32C), J11.1, J12.1, J13.1
IRQ: J1.B12 (12B), J2.A12 (12A), J3.A12 (12A), J4.A12 (12A), J5.A12 (12A), J6.A12 (12A)
NMI: J1.A12 (12A), J2.C12 (12C), J3.C12 (12C), J4.C12 (12C), J5.C12 (12C), J6.C12 (12C)
PHI1: J1.B30 (30B), J2.A30 (30A), J3.A30 (30A), J4.A30 (30A), J5.A30 (30A), J6.A30 (30A)
RAM.RW: J1.B31 (31B), J2.A31 (31A), J3.A31 (31A), J4.A31 (31A), J5.A31 (31A), J6.A31 (31A)
RDY: J1.A5 (5A), J2.C5 (5C), J3.C5 (5C), J4.C5 (5C), J5.C5 (5C), J6.C5 (5C)
RES: J1.B5 (5B), J2.A5 (5A), J3.A5 (5A), J4.A5 (5A), J5.A5 (5A), J6.A5 (5A)
RW: J1.A29 (29A), J2.C29 (29C), J3.C29 (29C), J4.C29 (29C), J5.C29 (29C), J6.C29 (29C)
SO: J1.A14 (14A), J2.C14 (14C), J3.C14 (14C), J4.C14 (14C), J5.C14 (14C), J6.C14 (14C)

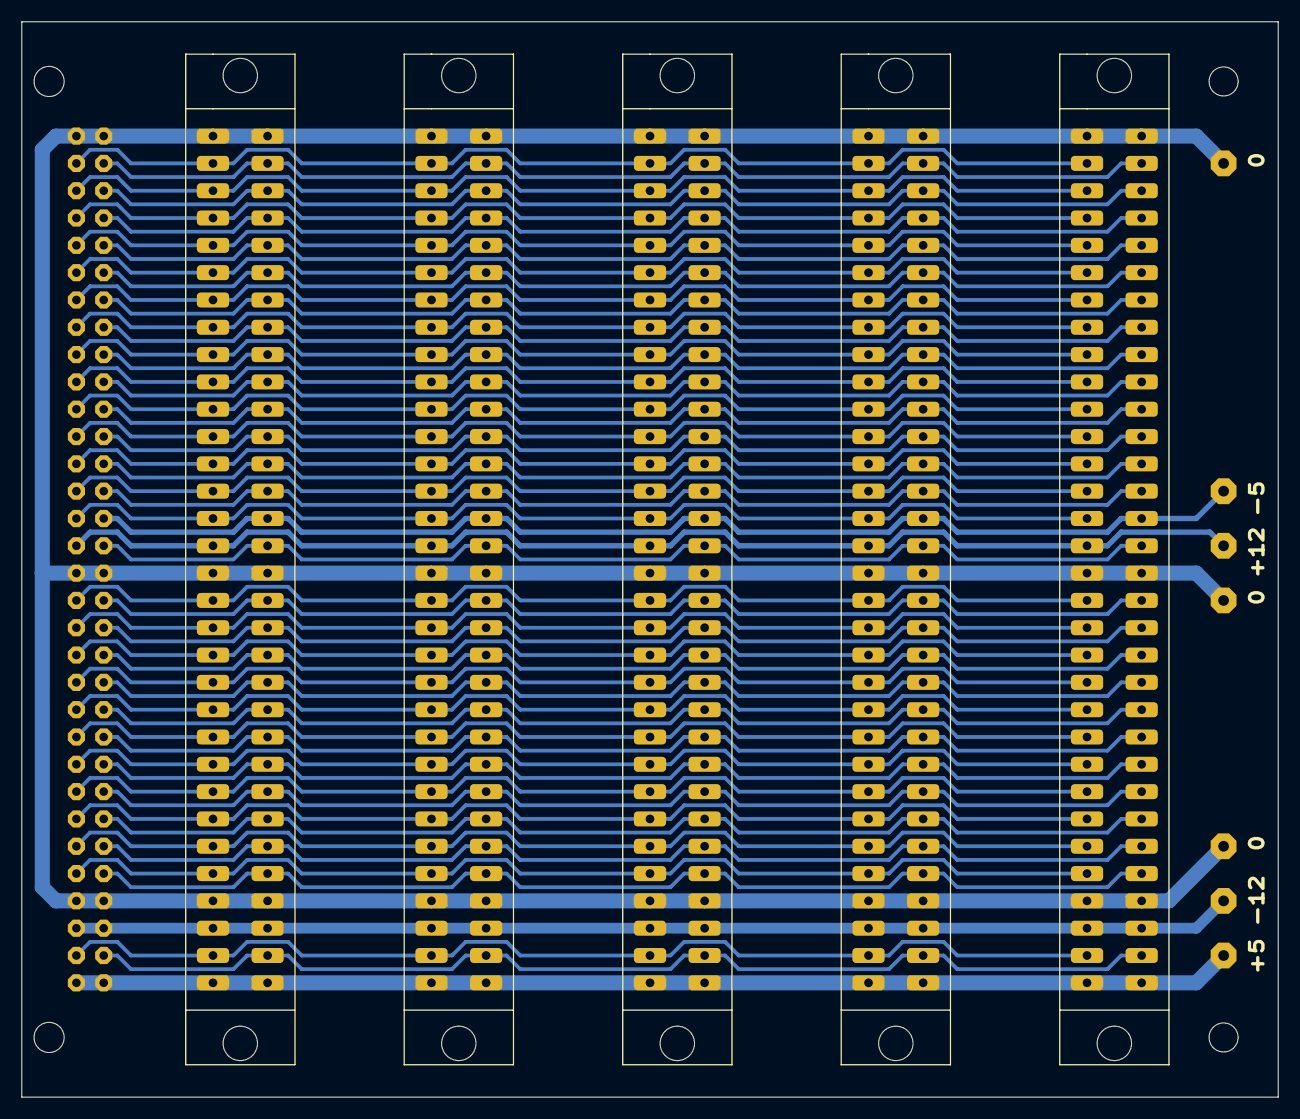
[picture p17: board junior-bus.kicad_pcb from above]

Board: 2 copper layers, 116.8 x 100.0 mm, 15 parts (1 on the bottom side), 57 nets.

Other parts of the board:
REF1, REF2: MountingHole_2.7mm_M2.5_ISO14580

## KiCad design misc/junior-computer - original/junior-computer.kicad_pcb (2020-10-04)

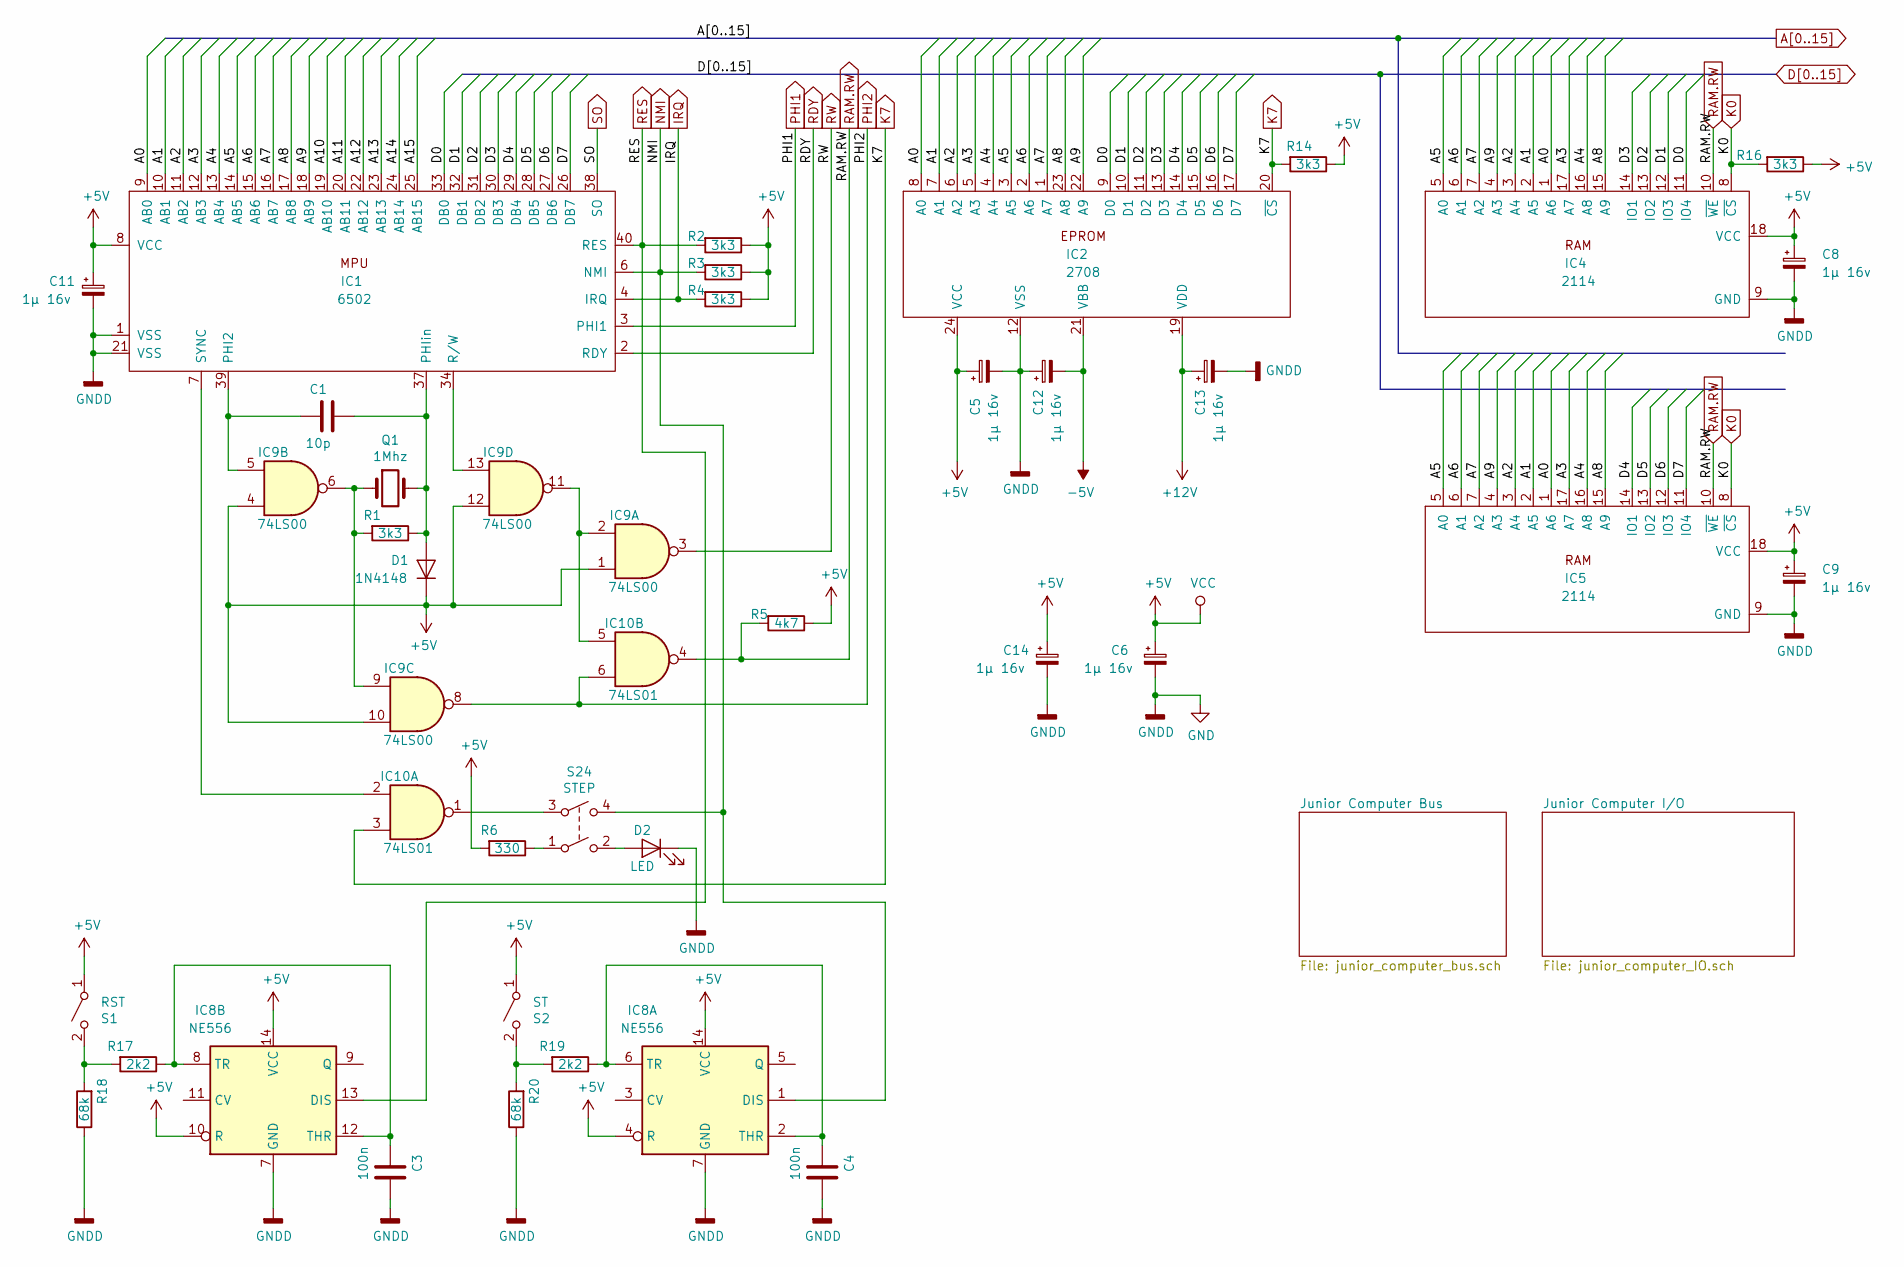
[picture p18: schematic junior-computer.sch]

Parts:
C1: 10p; CAP-2
C3, C4: 100n; CAP-3
C5: 1µ 16v; CAP-POL-2
C6, C9, C11, C14: 1µ 16v; CAP-POL-3
C8, C12, C13: 1µ 16v; CAP-POL-1.5
D1: 1N4148; Diod-4
D2: LED; Digitast-LED
IC1: 6502; DIL-40
IC2: 2708; DIL-24
IC4, IC5: 2114; DIL-18
IC8: NE556; DIL-14
IC9: 74LS00; DIL-14
IC10: 74LS01; DIL-14
Q1: 1Mhz; Quartz
R1, R2, R3, R4, R14, R16: 3k3; Res-5
R5: 4k7; Res-5
R6: 330; Res-5
R17, R19: 2k2; Res-5
R18, R20: 68k; Res-5
S1: RST; Digitast
S2: ST; Digitast
S24: STEP; SW-2T

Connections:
+5V: C5.1, C6.1, C8.1, C9.1, C11.1, C14.1, D1.1 (K), IC1.8 (VCC), IC2.24 (VCC), IC4.18 (VCC), IC5.18 (VCC), IC8.4 (R), IC8.10 (R), IC8.14 (VCC), IC9.1, IC9.4, IC9.10, IC9.12, IC9.14 (VCC), IC10.14 (VCC), R2.1, R3.1, R4.1, R5.1, R6.2, R14.1, R16.1, S1.1 (A), S2.1 (A); also elsewhere on the board
+12V: C13.1, IC2.19 (VDD); also elsewhere on the board
-5V: C12.2, IC2.21 (VBB); also elsewhere on the board
A0: IC1.9 (AB0), IC2.8 (A0), IC4.1 (A6), IC5.1 (A6); also elsewhere on the board
A1: IC1.10 (AB1), IC2.7 (A1), IC4.2 (A5), IC5.2 (A5); also elsewhere on the board
A2: IC1.11 (AB2), IC2.6 (A2), IC4.3 (A4), IC5.3 (A4); also elsewhere on the board
A3: IC1.12 (AB3), IC2.5 (A3), IC4.17 (A7), IC5.17 (A7); also elsewhere on the board
A4: IC1.13 (AB4), IC2.4 (A4), IC4.16 (A8), IC5.16 (A8); also elsewhere on the board
A5: IC1.14 (AB5), IC2.3 (A5), IC4.5 (A0), IC5.5 (A0); also elsewhere on the board
A6: IC1.15 (AB6), IC2.2 (A6), IC4.6 (A1), IC5.6 (A1); also elsewhere on the board
A7: IC1.16 (AB7), IC2.1 (A7), IC4.7 (A2), IC5.7 (A2); also elsewhere on the board
A8: IC1.17 (AB8), IC2.23 (A8), IC4.15 (A9), IC5.15 (A9); also elsewhere on the board
A9: IC1.18 (AB9), IC2.22 (A9), IC4.4 (A3), IC5.4 (A3); also elsewhere on the board
A10: IC1.19 (AB10); also elsewhere on the board
A11: IC1.20 (AB11); also elsewhere on the board
A12: IC1.22 (AB12); also elsewhere on the board
A13: IC1.23 (AB13); also elsewhere on the board
A14: IC1.24 (AB14); also elsewhere on the board
A15: IC1.25 (AB15); also elsewhere on the board
D0: IC1.33 (DB0), IC2.9 (D0), IC4.11 (IO4); also elsewhere on the board
D1: IC1.32 (DB1), IC2.10 (D1), IC4.12 (IO3); also elsewhere on the board
D2: IC1.31 (DB2), IC2.11 (D2), IC4.13 (IO2); also elsewhere on the board
D3: IC1.30 (DB3), IC2.13 (D3), IC4.14 (IO1); also elsewhere on the board
D4: IC1.29 (DB4), IC2.14 (D4), IC5.14 (IO1); also elsewhere on the board
D5: IC1.28 (DB5), IC2.15 (D5), IC5.13 (IO2); also elsewhere on the board
D6: IC1.27 (DB6), IC2.16 (D6), IC5.12 (IO3); also elsewhere on the board
D7: IC1.26 (DB7), IC2.17 (D7), IC5.11 (IO4); also elsewhere on the board
GND: C3.1, C4.1, C5.2, C6.2, C8.2, C9.2, C11.2, C12.1, C13.2, C14.2, D2.1 (K), IC1.1 (VSS), IC1.21 (VSS), IC2.12 (VSS), IC4.9 (GND), IC5.9 (GND), IC8.7 (GND), IC9.7 (GND), IC10.7 (GND), R18.1, R20.1; also elsewhere on the board
IRQ: IC1.4 (IRQ), R4.2; also elsewhere on the board
K0: IC4.8 (~CS~), IC5.8 (~CS~), R16.2; also elsewhere on the board
K7: IC2.20 (~CS~), IC10.3, R14.2; also elsewhere on the board
NMI: IC1.6 (NMI), IC8.1 (DIS), R3.2, S24.4; also elsewhere on the board
unnamed: C1.1, D1.2 (A), IC1.37 (PHIin), Q1.2, R1.1
unnamed: C1.2, IC1.39 (PHI2), IC9.5
unnamed: C3.2, IC8.8 (TR), IC8.12 (THR), R17.1
unnamed: C4.2, IC8.2 (THR), IC8.6 (TR), R19.1
unnamed: D2.2 (A), S24.2
unnamed: IC1.7 (SYNC), IC10.2
unnamed: IC1.34 (R/W), IC9.13
unnamed: IC9.6, IC9.9, Q1.1, R1.2
unnamed: IC10.1, S24.3
unnamed: IC9.2, IC9.11, IC10.5
unnamed: R6.1, S24.1
unnamed: R17.2, R18.2, S1.2 (B)
unnamed: R19.2, R20.2, S2.2 (B)
PHI1: IC1.3 (PHI1); also elsewhere on the board
PHI2: IC9.8, IC10.6; also elsewhere on the board
RAM.RW: IC4.10 (~WE~), IC5.10 (~WE~), IC10.4, R5.2; also elsewhere on the board
RDY: IC1.2 (RDY); also elsewhere on the board
RES: IC1.40 (RES), IC8.13 (DIS), R2.2; also elsewhere on the board
RW: IC9.3; also elsewhere on the board
SO: IC1.38 (SO); also elsewhere on the board

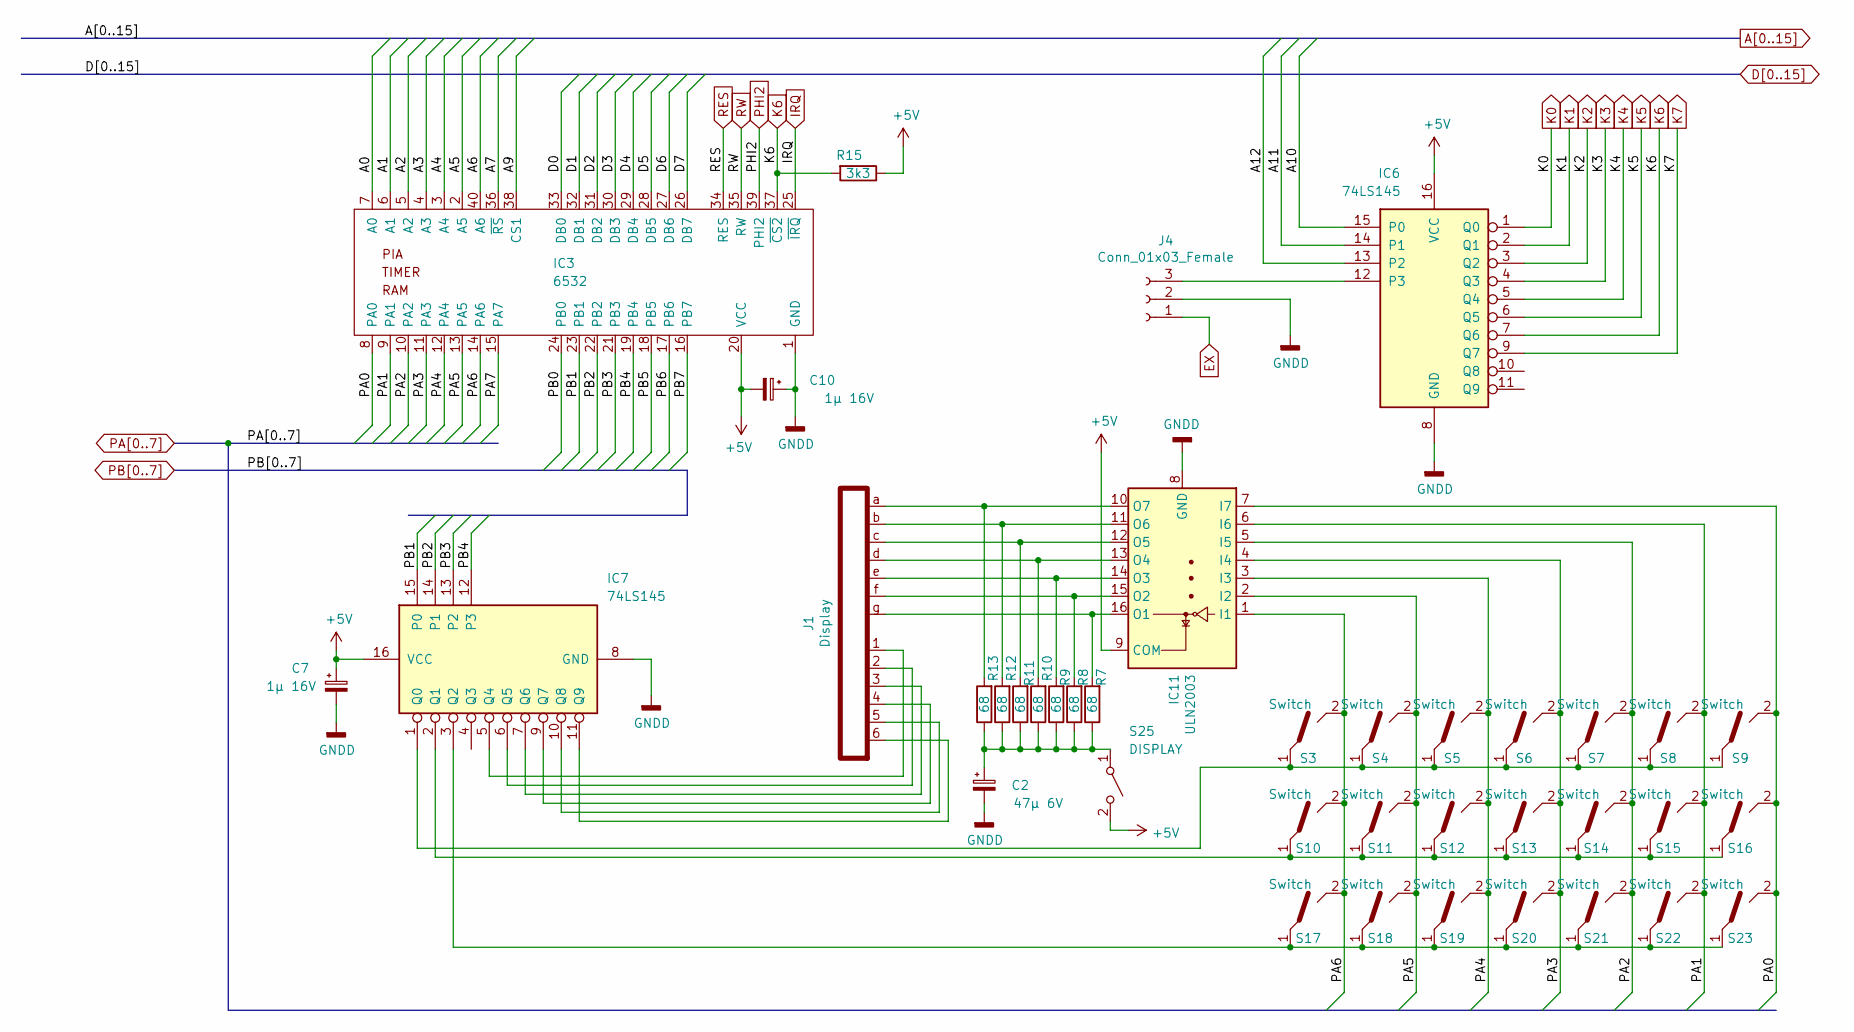
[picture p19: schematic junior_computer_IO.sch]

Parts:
C2: 47µ 6V; CAP-POL-5
C7: 1µ 16V; CAP-POL-3
C10: 1µ 16V; CAP-POL-2
IC3: 6532; DIL-40
IC6, IC7: 74LS145; DIL-16
IC11: ULN2003; DIL-16
J1: Display; Conn-Display-Bottom
J4: Conn_01x03_Female; Jumper-D-EX
R7, R8, R9, R10, R11, R12, R13: 68; Res-5
R15: 3k3; Res-5
S3, S4, S5, S6, S7, S8, S9, S10, S11, S12, S13, S14, S15, S16, S17, S18, S19, S20, S21, S22, S23: Switch; Digitast
S25: DISPLAY; SW-1T

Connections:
+5V: C7.1, C10.2, IC3.20 (VCC), IC6.16 (VCC), IC7.16 (VCC), IC11.9 (COM), R15.1, S25.2 (B); also elsewhere on the board
A0: IC3.7 (A0); also elsewhere on the board
A1: IC3.6 (A1); also elsewhere on the board
A2: IC3.5 (A2); also elsewhere on the board
A3: IC3.4 (A3); also elsewhere on the board
A4: IC3.3 (A4); also elsewhere on the board
A5: IC3.2 (A5); also elsewhere on the board
A6: IC3.40 (A6); also elsewhere on the board
A7: IC3.36 (~RS~); also elsewhere on the board
A9: IC3.38 (CS1); also elsewhere on the board
A10: IC6.15 (P0); also elsewhere on the board
A11: IC6.14 (P1); also elsewhere on the board
A12: IC6.13 (P2); also elsewhere on the board
D0: IC3.33 (DB0); also elsewhere on the board
D1: IC3.32 (DB1); also elsewhere on the board
D2: IC3.31 (DB2); also elsewhere on the board
D3: IC3.30 (DB3); also elsewhere on the board
D4: IC3.29 (DB4); also elsewhere on the board
D5: IC3.28 (DB5); also elsewhere on the board
D6: IC3.27 (DB6); also elsewhere on the board
D7: IC3.26 (DB7); also elsewhere on the board
EX: J4.1; also elsewhere on the board
GND: C2.2, C7.2, C10.1, IC3.1 (GND), IC6.8 (GND), IC7.8 (GND), IC11.8 (GND), J4.2; also elsewhere on the board
IRQ: IC3.25 (~IRQ~); also elsewhere on the board
K0: IC6.1 (Q0); also elsewhere on the board
K1: IC6.2 (Q1); also elsewhere on the board
K2: IC6.3 (Q2); also elsewhere on the board
K3: IC6.4 (Q3); also elsewhere on the board
K4: IC6.5 (Q4); also elsewhere on the board
K5: IC6.6 (Q5); also elsewhere on the board
K6: IC3.37 (~CS2~), IC6.7 (Q6), R15.2; also elsewhere on the board
K7: IC6.9 (Q7); also elsewhere on the board
unnamed: C2.1, R7.1, R8.1, R9.1, R10.1, R11.1, R12.1, R13.1, S25.1 (A)
unnamed: IC6.12 (P3), J4.3
unnamed: IC7.1 (Q0), S3.1, S4.1, S5.1, S6.1, S7.1, S8.1, S9.1
unnamed: IC7.2 (Q1), S10.1, S11.1, S12.1, S13.1, S14.1, S15.1, S16.1
unnamed: IC7.3 (Q2), S17.1, S18.1, S19.1, S20.1, S21.1, S22.1, S23.1
unnamed: IC7.5 (Q4), J1.1
unnamed: IC7.6 (Q5), J1.2
unnamed: IC7.7 (Q6), J1.3
unnamed: IC7.9 (Q7), J1.4
unnamed: IC7.10 (Q8), J1.5
unnamed: IC7.11 (Q9), J1.6
unnamed: IC11.10 (O7), J1.a, R13.2
unnamed: IC11.11 (O6), J1.b, R12.2
unnamed: IC11.12 (O5), J1.c, R11.2
unnamed: IC11.13 (O4), J1.d, R10.2
unnamed: IC11.14 (O3), J1.e, R9.2
unnamed: IC11.15 (O2), J1.f, R8.2
unnamed: IC11.16 (O1), J1.g, R7.2
PA0: IC3.8 (PA0), IC11.7 (I7), S9.2, S16.2, S23.2; also elsewhere on the board
PA1: IC3.9 (PA1), IC11.6 (I6), S8.2, S15.2, S22.2; also elsewhere on the board
PA2: IC3.10 (PA2), IC11.5 (I5), S7.2, S14.2, S21.2; also elsewhere on the board
PA3: IC3.11 (PA3), IC11.4 (I4), S6.2, S13.2, S20.2; also elsewhere on the board
PA4: IC3.12 (PA4), IC11.3 (I3), S5.2, S12.2, S19.2; also elsewhere on the board
PA5: IC3.13 (PA5), IC11.2 (I2), S4.2, S11.2, S18.2; also elsewhere on the board
PA6: IC3.14 (PA6), IC11.1 (I1), S3.2, S10.2, S17.2; also elsewhere on the board
PA7: IC3.15 (PA7); also elsewhere on the board
PB0: IC3.24 (PB0); also elsewhere on the board
PB1: IC3.23 (PB1), IC7.15 (P0); also elsewhere on the board
PB2: IC3.22 (PB2), IC7.14 (P1); also elsewhere on the board
PB3: IC3.21 (PB3), IC7.13 (P2); also elsewhere on the board
PB4: IC3.19 (PB4), IC7.12 (P3); also elsewhere on the board
PB5: IC3.18 (PB5); also elsewhere on the board
PB6: IC3.17 (PB6); also elsewhere on the board
PB7: IC3.16 (PB7); also elsewhere on the board
PHI2: IC3.39 (PHI2); also elsewhere on the board
RES: IC3.34 (RES); also elsewhere on the board
RW: IC3.35 (RW); also elsewhere on the board

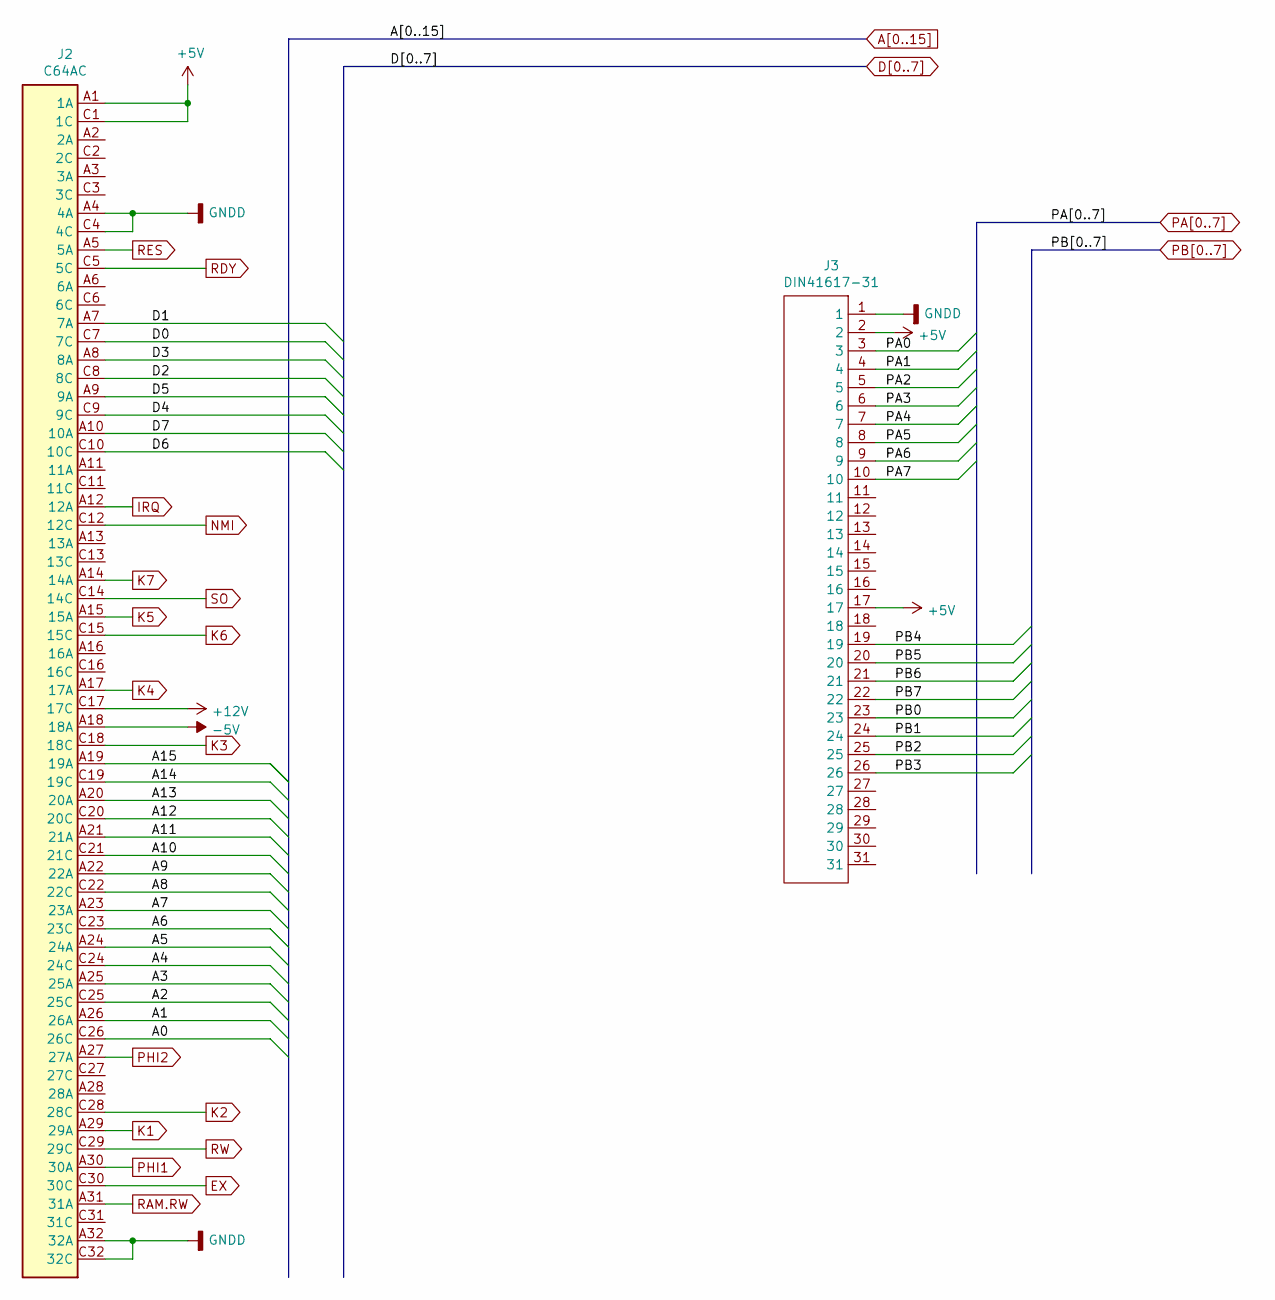
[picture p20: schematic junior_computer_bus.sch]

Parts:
J2: C64AC; DIN-41612-AC
J3: DIN41617-31; DIN-41617-31-F

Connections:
+5V: J2.A1 (1A), J2.C1 (1C), J3.2, J3.17; also elsewhere on the board
+12V: J2.C17 (17C); also elsewhere on the board
-5V: J2.A18 (18A); also elsewhere on the board
A0: J2.C26 (26C); also elsewhere on the board
A1: J2.A26 (26A); also elsewhere on the board
A2: J2.C25 (25C); also elsewhere on the board
A3: J2.A25 (25A); also elsewhere on the board
A4: J2.C24 (24C); also elsewhere on the board
A5: J2.A24 (24A); also elsewhere on the board
A6: J2.C23 (23C); also elsewhere on the board
A7: J2.A23 (23A); also elsewhere on the board
A8: J2.C22 (22C); also elsewhere on the board
A9: J2.A22 (22A); also elsewhere on the board
A10: J2.C21 (21C); also elsewhere on the board
A11: J2.A21 (21A); also elsewhere on the board
A12: J2.C20 (20C); also elsewhere on the board
A13: J2.A20 (20A); also elsewhere on the board
A14: J2.C19 (19C); also elsewhere on the board
A15: J2.A19 (19A); also elsewhere on the board
D0: J2.C7 (7C); also elsewhere on the board
D1: J2.A7 (7A); also elsewhere on the board
D2: J2.C8 (8C); also elsewhere on the board
D3: J2.A8 (8A); also elsewhere on the board
D4: J2.C9 (9C); also elsewhere on the board
D5: J2.A9 (9A); also elsewhere on the board
D6: J2.C10 (10C); also elsewhere on the board
D7: J2.A10 (10A); also elsewhere on the board
EX: J2.C30 (30C); also elsewhere on the board
GND: J2.A4 (4A), J2.A32 (32A), J2.C4 (4C), J2.C32 (32C), J3.1; also elsewhere on the board
IRQ: J2.A12 (12A); also elsewhere on the board
K1: J2.A29 (29A); also elsewhere on the board
K2: J2.C28 (28C); also elsewhere on the board
K3: J2.C18 (18C); also elsewhere on the board
K4: J2.A17 (17A); also elsewhere on the board
K5: J2.A15 (15A); also elsewhere on the board
K6: J2.C15 (15C); also elsewhere on the board
K7: J2.A14 (14A); also elsewhere on the board
NMI: J2.C12 (12C); also elsewhere on the board
PA0: J3.3; also elsewhere on the board
PA1: J3.4; also elsewhere on the board
PA2: J3.5; also elsewhere on the board
PA3: J3.6; also elsewhere on the board
PA4: J3.7; also elsewhere on the board
PA5: J3.8; also elsewhere on the board
PA6: J3.9; also elsewhere on the board
PA7: J3.10; also elsewhere on the board
PB0: J3.23; also elsewhere on the board
PB1: J3.24; also elsewhere on the board
PB2: J3.25; also elsewhere on the board
PB3: J3.26; also elsewhere on the board
PB4: J3.19; also elsewhere on the board
PB5: J3.20; also elsewhere on the board
PB6: J3.21; also elsewhere on the board
PB7: J3.22; also elsewhere on the board
PHI1: J2.A30 (30A); also elsewhere on the board
PHI2: J2.A27 (27A); also elsewhere on the board
RAM.RW: J2.A31 (31A); also elsewhere on the board
RDY: J2.C5 (5C); also elsewhere on the board
RES: J2.A5 (5A); also elsewhere on the board
RW: J2.C29 (29C); also elsewhere on the board
SO: J2.C14 (14C); also elsewhere on the board

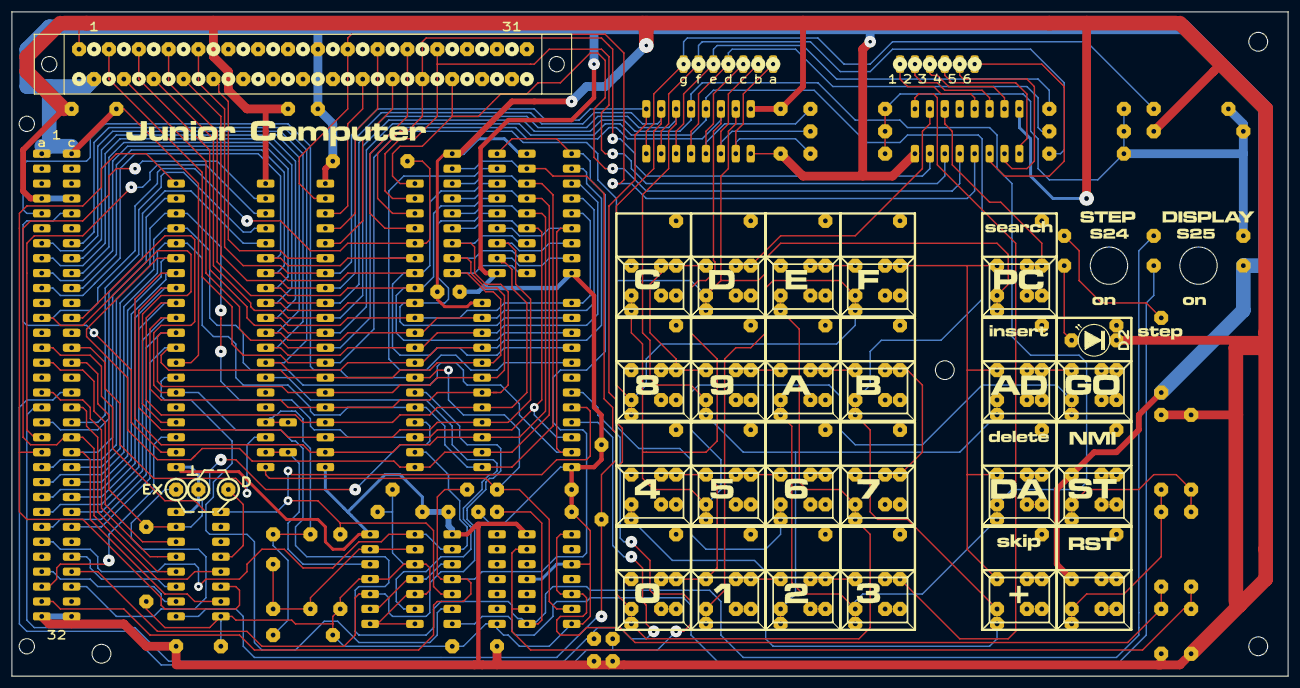
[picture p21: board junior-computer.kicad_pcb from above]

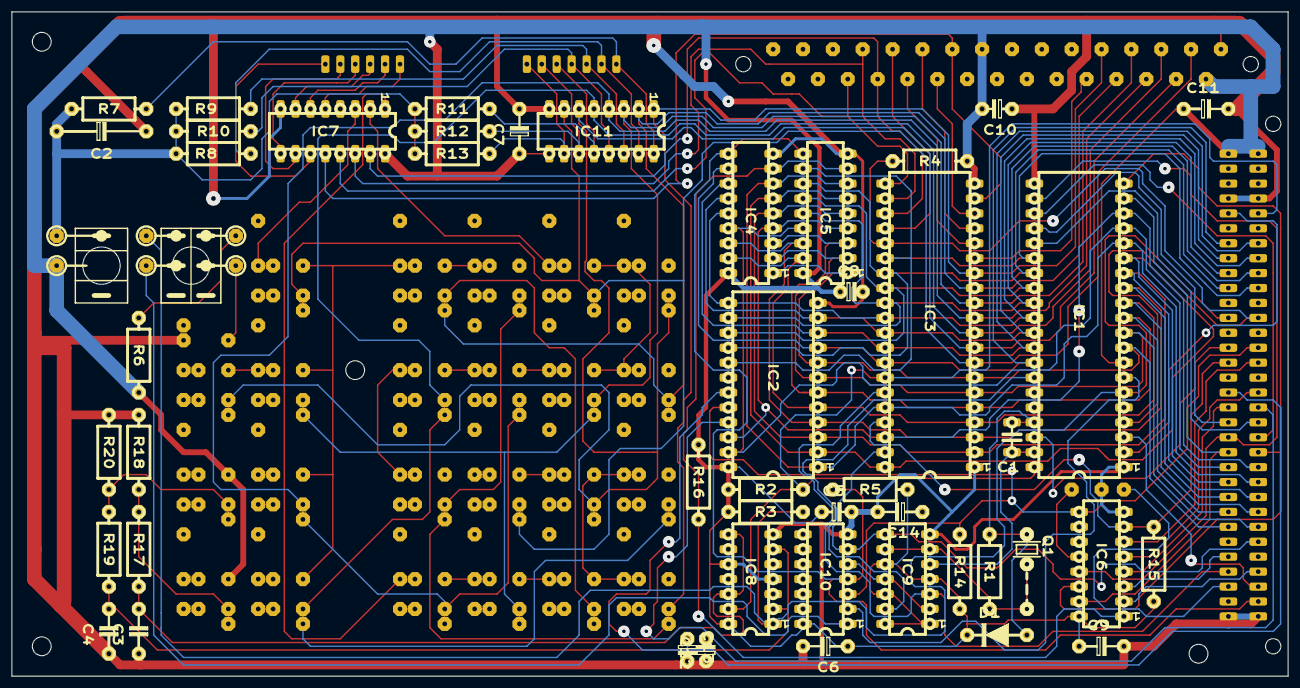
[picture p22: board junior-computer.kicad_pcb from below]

Board: 2 copper layers, 217.2 x 113.0 mm, 78 parts (49 on the bottom side), 93 nets.

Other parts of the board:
Ref**: Val**; lettrages2

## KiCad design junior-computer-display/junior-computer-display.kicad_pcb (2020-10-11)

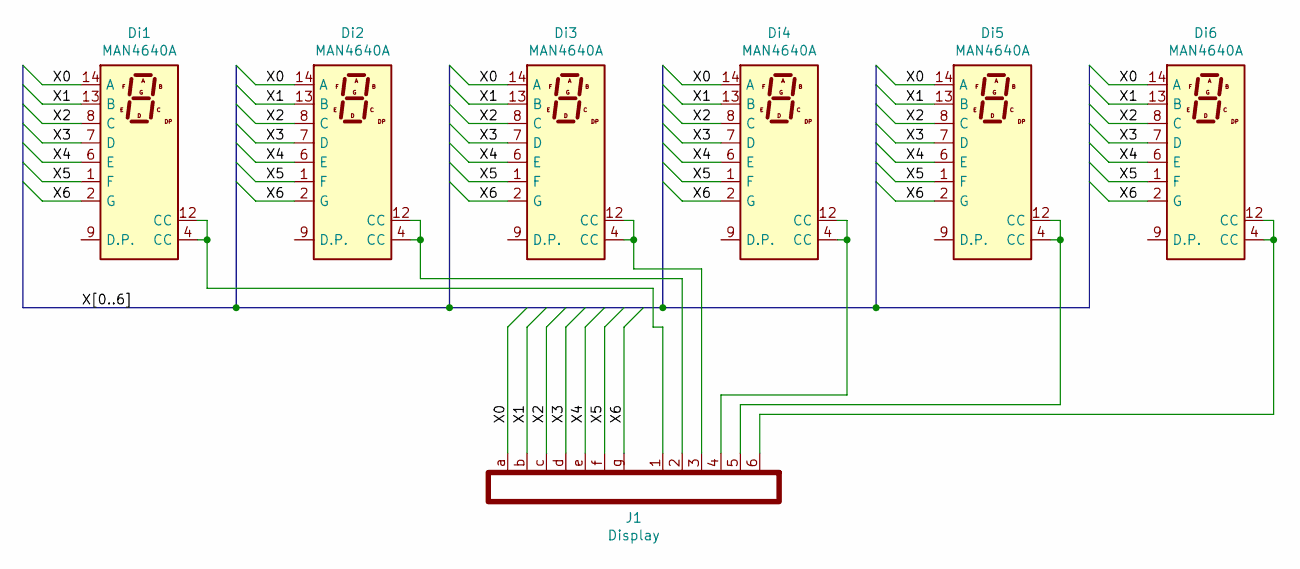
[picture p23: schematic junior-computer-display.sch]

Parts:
Di1, Di2, Di3, Di4, Di5, Di6: MAN4640A; 7SEGMENT
J1: Display; Conn-Display-Top

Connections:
/X0: Di1.14 (A), Di2.14 (A), Di3.14 (A), Di4.14 (A), Di5.14 (A), Di6.14 (A), J1.a
/X1: Di1.13 (B), Di2.13 (B), Di3.13 (B), Di4.13 (B), Di5.13 (B), Di6.13 (B), J1.b
/X2: Di1.8 (C), Di2.8 (C), Di3.8 (C), Di4.8 (C), Di5.8 (C), Di6.8 (C), J1.c
/X3: Di1.7 (D), Di2.7 (D), Di3.7 (D), Di4.7 (D), Di5.7 (D), Di6.7 (D), J1.d
/X4: Di1.6 (E), Di2.6 (E), Di3.6 (E), Di4.6 (E), Di5.6 (E), Di6.6 (E), J1.e
/X5: Di1.1 (F), Di2.1 (F), Di3.1 (F), Di4.1 (F), Di5.1 (F), Di6.1 (F), J1.f
/X6: Di1.2 (G), Di2.2 (G), Di3.2 (G), Di4.2 (G), Di5.2 (G), Di6.2 (G), J1.g
unnamed: Di1.4 (CC), Di1.12 (CC), J1.1
unnamed: Di2.4 (CC), Di2.12 (CC), J1.2
unnamed: Di3.4 (CC), Di3.12 (CC), J1.3
unnamed: Di4.4 (CC), Di4.12 (CC), J1.4
unnamed: Di5.4 (CC), Di5.12 (CC), J1.5
unnamed: Di6.4 (CC), Di6.12 (CC), J1.6

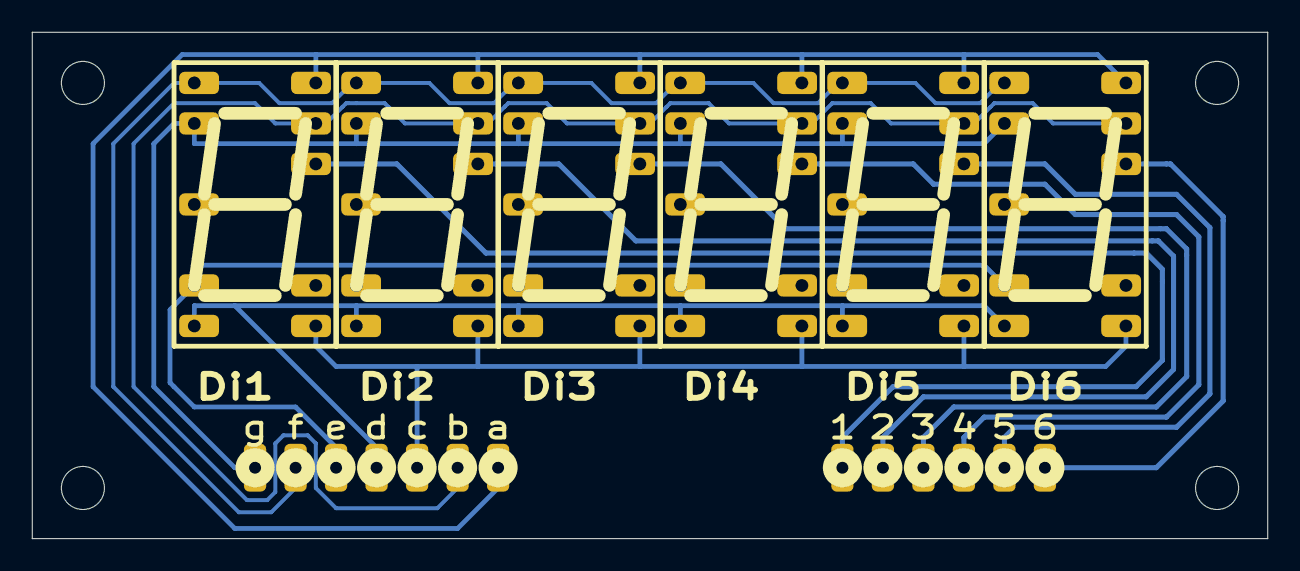
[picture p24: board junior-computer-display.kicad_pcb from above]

Board: 2 copper layers, 77.5 x 31.8 mm, 7 parts (0 on the bottom side), 13 nets.

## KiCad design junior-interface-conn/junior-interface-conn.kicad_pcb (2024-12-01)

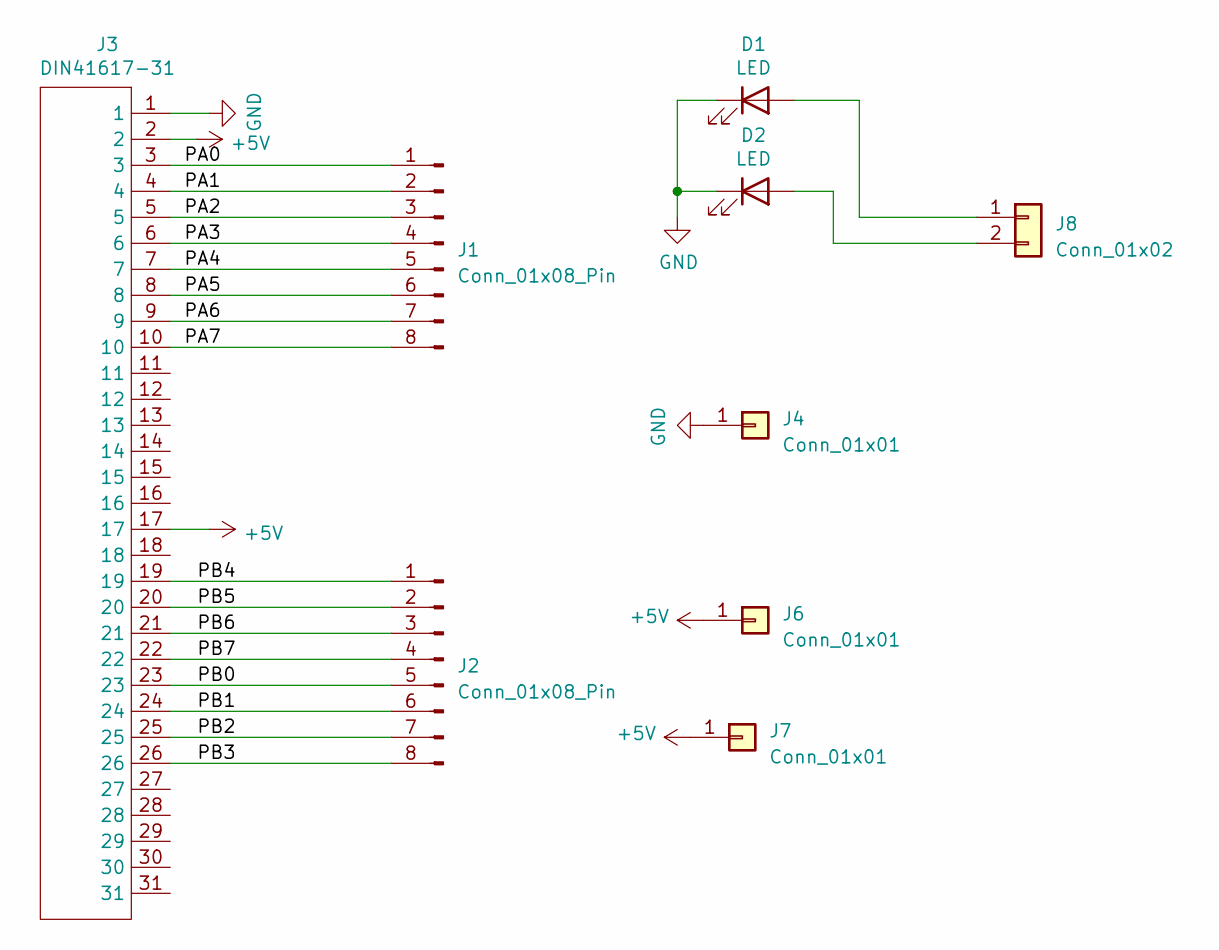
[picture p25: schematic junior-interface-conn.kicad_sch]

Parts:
D1, D2: LED
J1, J2: Conn_01x08_Pin; CONN-8
J3: DIN41617-31; DIN-41617-31-M
J4, J6, J7: Conn_01x01; CONN-1
J8: Conn_01x02; CONN-2-L

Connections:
+5V: J3.2, J3.17, J6.1, J7.1
/PA0: J1.1, J3.3
/PA1: J1.2, J3.4
/PA2: J1.3, J3.5
/PA3: J1.4, J3.6
/PA4: J1.5, J3.7
/PA5: J1.6, J3.8
/PA6: J1.7, J3.9
/PA7: J1.8, J3.10
/PB0: J2.5, J3.23
/PB1: J2.6, J3.24
/PB2: J2.7, J3.25
/PB3: J2.8, J3.26
/PB4: J2.1, J3.19
/PB5: J2.2, J3.20
/PB6: J2.3, J3.21
/PB7: J2.4, J3.22
GND: D1.1 (K), D2.1 (K), J3.1, J4.1
unnamed: D1.2 (A), J8.1
unnamed: D2.2 (A), J8.2

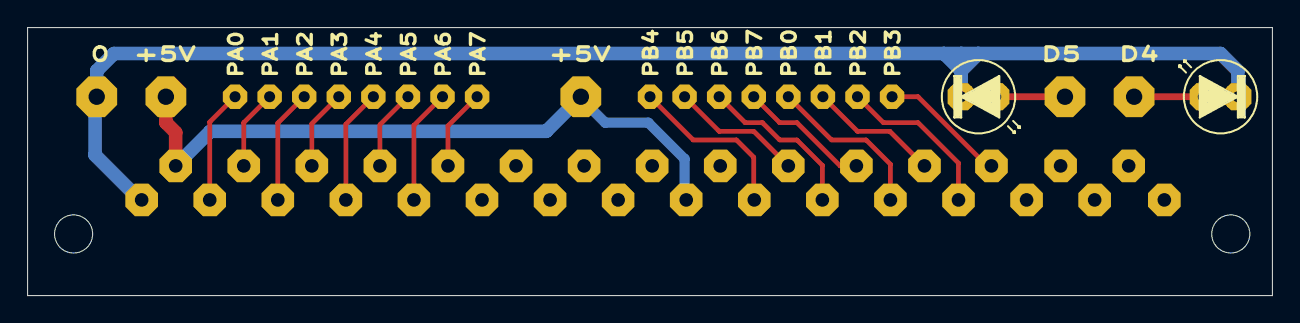
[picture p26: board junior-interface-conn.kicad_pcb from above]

Board: 2 copper layers, 91.4 x 19.7 mm, 9 parts (1 on the bottom side), 20 nets.

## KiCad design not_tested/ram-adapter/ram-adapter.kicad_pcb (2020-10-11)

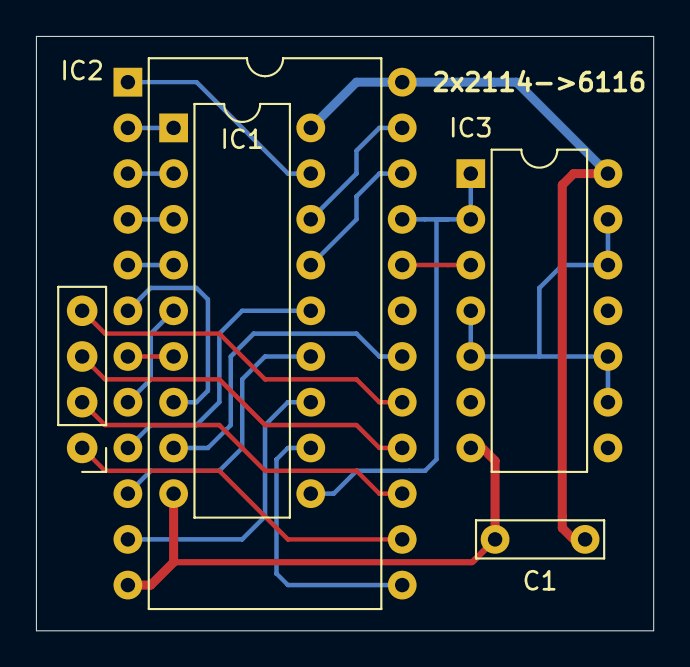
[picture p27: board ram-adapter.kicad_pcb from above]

Board: 2 copper layers, 34.3 x 33.0 mm, 5 parts (0 on the bottom side), 24 nets.

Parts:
C1: 100nf; C_Rect_L7.0mm_W2.0mm_P5.00mm
IC1: 2114; DIP-18_W7.62mm
IC2: 6116; DIP-24_W15.24mm
IC3: 74LS00; DIP-14_W7.62mm
J1: Conn_01x04_Male; Pin_Header_Straight_1x04_Pitch2.54mm

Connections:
GND: C1.2, IC1.9, IC2.12, IC3.7
unnamed: IC1.1, IC2.2
unnamed: IC1.2, IC2.3
unnamed: IC1.3, IC2.4
unnamed: IC1.4, IC2.5
unnamed: IC1.5, IC2.8
unnamed: IC1.6, IC2.7
unnamed: IC1.7, IC2.6
unnamed: IC1.8, IC2.18
unnamed: IC1.10, IC2.21, IC3.1, IC3.2
unnamed: IC1.11, IC2.13
unnamed: IC1.12, IC2.11
unnamed: IC1.13, IC2.10
unnamed: IC1.14, IC2.9
unnamed: IC1.15, IC2.22
unnamed: IC1.16, IC2.23
unnamed: IC1.17, IC2.1
unnamed: IC2.14, J1.1
unnamed: IC2.15, J1.2
unnamed: IC2.16, J1.3
unnamed: IC2.17, J1.4
unnamed: IC2.20, IC3.3
unnamed: IC3.4, IC3.5, IC3.9, IC3.10, IC3.12, IC3.13
VCC: C1.1, IC1.18, IC2.24, IC3.14

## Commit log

2020-10-03 routage complet
    [junior-computer.kicad_pcb, junior-computer.sch]
2020-10-03 amelioration dessin pistes
    [junior-computer.kicad_pcb, junior-computer.sch]
2020-10-07 modifs schema
    [junior-computer.kicad_pcb, junior-computer.sch, junior_computer_IO.sch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]
2020-10-08 correction empreintes
    [junior-computer.kicad_pcb, junior-computer.sch]
2020-10-09 correction stencil
    [junior-computer - Copie.kicad_pcb, junior-computer.sch]
2020-10-10 finition platine
    [junior-computer-bom.ods, junior-computer.sch]
2020-10-10 ram adapter
    [junior-computer-display.kicad_pcb, junior-computer.kicad_pcb, ram-adapter.kicad_pcb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]
2020-10-11 version commandée
    [junior-computer-B_Cu.gbr, junior-computer-B_Mask.gbr, junior-computer-B_Paste.gbr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]
2020-10-24 junior interface
    [junior-interface.sch, junior-internal-bus.kicad_pcb, junior-internal-bus.sch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]
2020-10-25 junior interface schema
    [junior-interface.sch, junior_interface_busext.sch, junior_interface_via.sch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]
2020-10-25 junior interface routage
    [junior-interface.sch, junior_interface_busext.sch, junior_interface_via.sch]
2020-10-31 junior interface routage complet
    [junior-interface.sch, junior_interface_via.sch, juniour_interface_out.sch]
2020-10-31 junior interface modifs
    [junior-interface.sch]
2020-11-03 junior bus
    [junior-bus.kicad_pcb, junior-bus.sch, junior-interface.sch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]
2020-11-04 junior ram
    [junior-bus.kicad_pcb, junior-ram.kicad_pcb, junior-ram.sch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]
2020-11-05 junior ram routage complet
    [junior-ram.kicad_pcb, junior_ram_main.sch]
2024-12-01 junior interface update
    [bom-junior-interface.csv, junior-bus.kicad_pcb, junior-bus.sch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]
2024-12-08 update Junior Bus subproject
    [junior-bus.kicad_pcb, junior-bus.kicad_sch, junior-bus.sch]
2024-12-08 fix - correct central M3.2 hole position
    [junior-interface-B_Cu.gbr, junior-interface-B_Mask.gbr, junior-interface-B_Paste.gbr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]
2024-12-08 fix - bad DIN41612 footprint, bad distance between connectors
    [junior-internal-bus-B_Cu.gbr, junior-internal-bus-B_Mask.gbr, junior-internal-bus-B_Paste.gbr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]
2024-12-08 add junior-universal-memory subproject / remove junior-ram subproject
    [address-decoding.kicad_sch, junior-ram.kicad_pcb, junior-ram.sch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]
2024-12-21 update status of bus&memory boards
    [address-decoding.kicad_sch, junior-bus.kicad_pcb, junior-bus.kicad_sch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]
2024-12-21 add REAdME
    [address-decoding.kicad_sch, junior-universal-memory.kicad_sch, memory-bank.kicad_sch]
2024-12-21 add memory board picture
